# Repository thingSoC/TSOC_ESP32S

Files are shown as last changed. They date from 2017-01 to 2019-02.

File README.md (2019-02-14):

# TSOC_ESP32S - thingSoC Wi-Fi Radio Module :

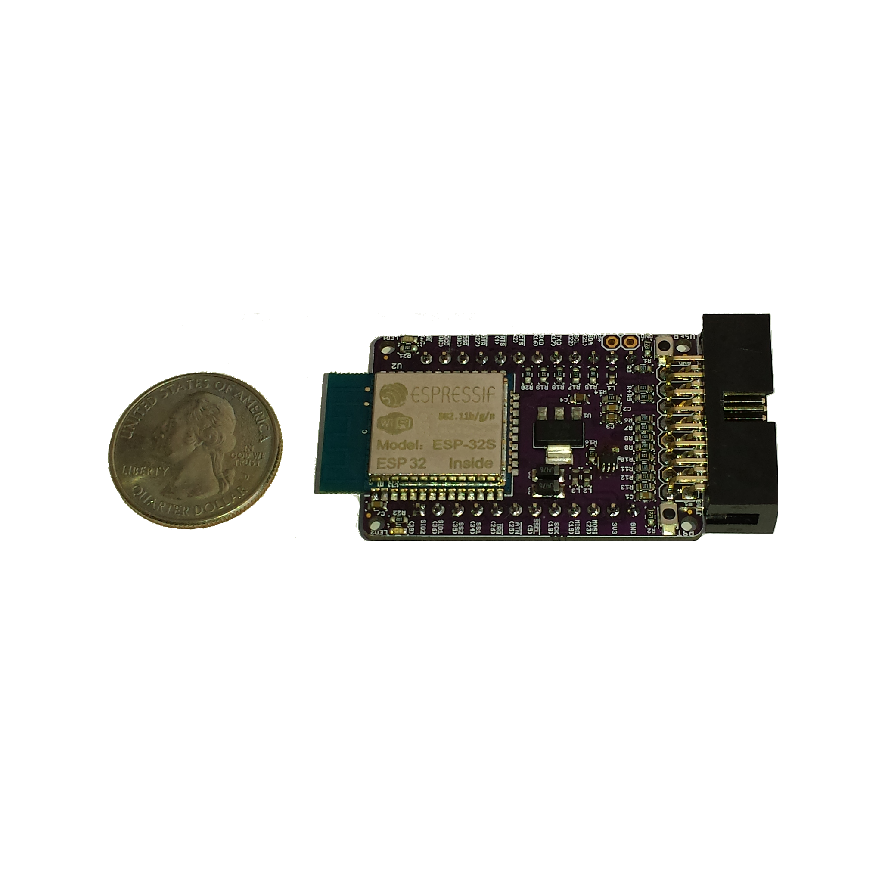
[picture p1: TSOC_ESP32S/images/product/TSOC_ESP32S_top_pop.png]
thingSoC TSOC_ESP32S
[TSOC_ESP32S](https://github.com/thingSoC/TSOC_ESP32S)

---------------------------------------

## TSOC_ESP32S Status <a name="TSOC_ESP32S_status"/>

**11/06/2016:** 
Revision 1.0 - Initial Layout released to OSHpark

---------------------------------------
## TSOC_ESP32S Model Images

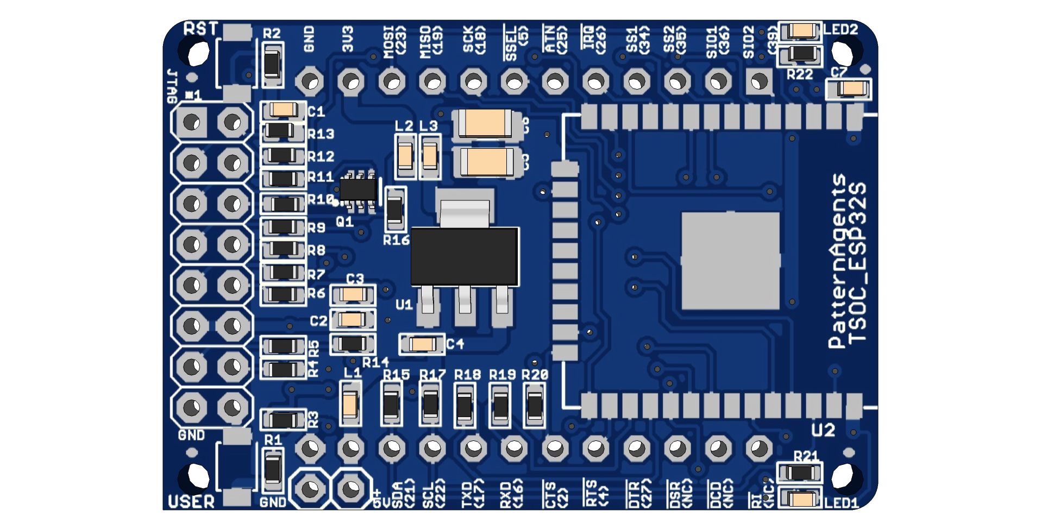
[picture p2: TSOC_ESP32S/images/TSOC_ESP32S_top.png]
thingSoC TSOC_ESP32S
[TSOC_ESP32S](https://github.com/thingSoC/TSOC_ESP32S)

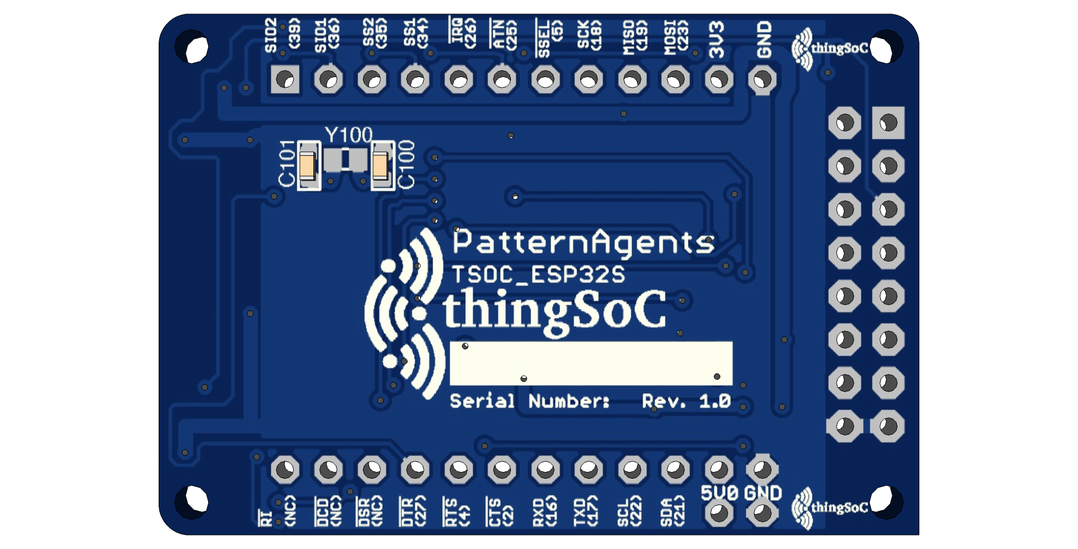
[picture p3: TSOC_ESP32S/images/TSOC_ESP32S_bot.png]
thingSoC TSOC_ESP32S
[TSOC_ESP32S](https://github.com/thingSoC/TSOC_ESP32S)

---------------------------------------

## TSOC_ESP32S Documentation Index <a name="TSOC_ESP32S_documentation_index"/>

[TSOC_ESP32S Project](http://thingsoc.github.io/projects/TSOC_ESP32S.html)

[TSOC_ESP32S Hardware](https://github.com/thingSoC/TSOC_ESP32S/tree/master/TSOC_ESP32S/hardware)

---------------------------------------

## thingSoC Documentation Index <a name="thingSoC_documentation_index"/>

[thingSoC Organization Website](http://thingSoC.github.io)

[thingSoC FAQ - Frequently Asked Questions](http://thingsoc.github.io/support/faq.html)

---------------------------------------

[thingSoC 
*thingSoC*](http://thingsoc.github.io)

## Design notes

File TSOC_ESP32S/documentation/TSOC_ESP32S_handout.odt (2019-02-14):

thingSoC ESP32S Board

Thank you for purchasing a TSOC_ESP32S board!
Please see the Getting Started Guide at :
https://github.com/thingSoC/TSOC_ESP32S (https://github.com/thingSoC/TSOC_NEOLED)
It has complete instructions and examples to download.

thingSoC ESP32S Board

Thank you for purchasing a TSOC_ESP32S board!
Please see the Getting Started Guide at :
https://github.com/thingSoC/TSOC_ESP32S (https://github.com/thingSoC/TSOC_NEOLED)
It has complete instructions and examples to download.

thingSoC ESP32S Board

Thank you for purchasing a TSOC_ESP32S board!
Please see the Getting Started Guide at :
https://github.com/thingSoC/TSOC_ESP32S (https://github.com/thingSoC/TSOC_NEOLED)
It has complete instructions and examples to download.

thingSoC ESP32S Board

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

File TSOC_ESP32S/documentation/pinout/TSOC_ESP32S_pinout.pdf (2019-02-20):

Sheet1

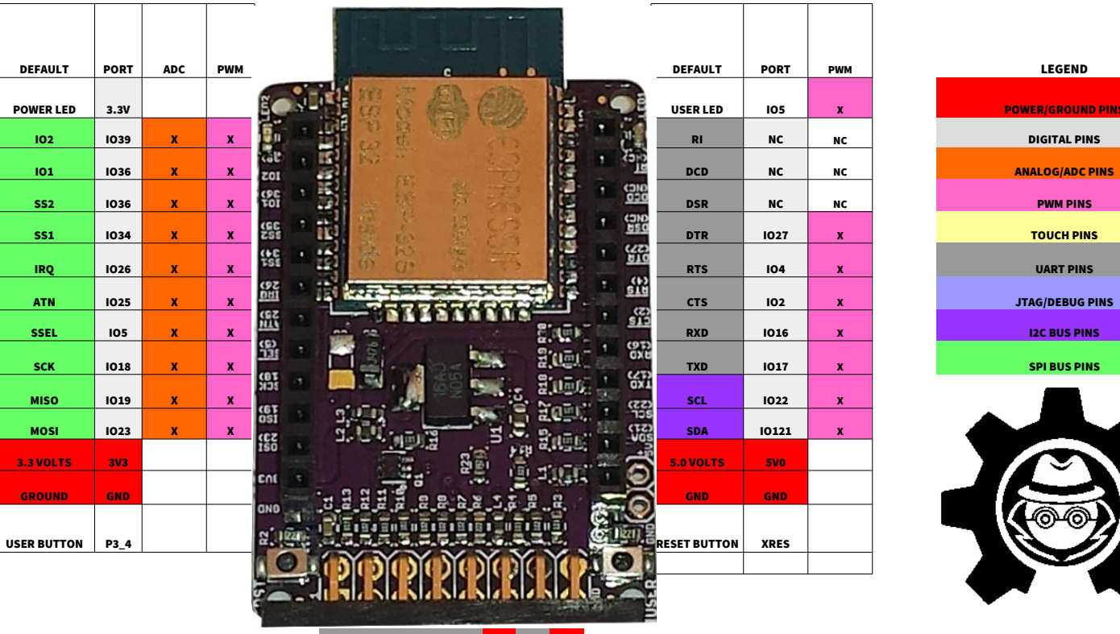
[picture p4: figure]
DIGITAL PINS; DCD; ANALOG/ADC PINS; DSR; PWM PINS; DTR; TOUCH PINS; IRQ; RTS; UART PINS; ATN; CTS; JTAG/DEBUG PINS; SSEL; RXD; I2C BUS PINS; SCK; TXD; SPI BUS PINS; MISO; SCL; MOSI; SDA; 3.3 VOLTS; 5.0 VOLTS; GROUND; GND; USER BUTTON; RESET BUTTON; XRES

Page 1

DEFAULT | PORT | ADC | PWM | DEFAULT | PORT | PWM | LEGEND
POWER LED | 3.3V | | | USER LED | IO5 | X | POWER/GROUND PINS

DSR1
RTS1

DTR1

TXD1 (IO3)

RXD1 (IO1)

5V0

CTS1
GND

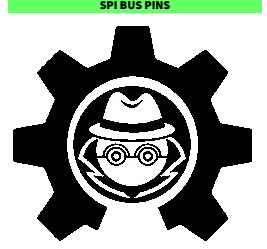
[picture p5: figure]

# ESP32 Wi-Fi Radio

DEBUG

SCL1 (IO12)
RESET#

SWDCLK (IO13)
SWDIO (IO14)

VCC

SDA1 (IO15)

GND

# http://github.com/thingSoC

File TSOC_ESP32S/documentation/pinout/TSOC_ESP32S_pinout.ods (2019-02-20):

DEFAULT | PORT | ADC | PWM |  |  |  |  |  |  |  |  | DEFAULT | PORT | PWM | LEGEND
POWER LED | 3.3V |  |  |  |  |  |  |  |  |  |  | USER LED | IO5 | X | POWER/GROUND PINS
IO2 | IO39 | X | X |  |  |  |  |  |  |  |  | RI | NC | NC | DIGITAL PINS
IO1 | IO36 | X | X |  |  |  |  |  |  |  |  | DCD | NC | NC | ANALOG/ADC PINS
SS2 | IO36 | X | X |  |  |  |  |  |  |  |  | DSR | NC | NC | PWM PINS
SS1 | IO34 | X | X |  |  |  |  |  |  |  |  | DTR | IO27 | X | TOUCH PINS
IRQ | IO26 | X | X |  |  |  |  |  |  |  |  | RTS | IO4 | X | UART PINS
ATN | IO25 | X | X |  |  |  |  |  |  |  |  | CTS | IO2 | X | JTAG/DEBUG PINS
SSEL | IO5 | X | X |  |  |  |  |  |  |  |  | RXD | IO16 | X | I2C BUS PINS
SCK | IO18 | X | X |  |  |  |  |  |  |  |  | TXD | IO17 | X | SPI BUS PINS
MISO | IO19 | X | X |  |  |  |  |  |  |  |  | SCL | IO22 | X
MOSI | IO23 | X | X |  |  |  |  |  |  |  |  | SDA | IO121 | X
3.3 VOLTS | 3V3 |  |  |  |  |  |  |  |  |  |  | 5.0 VOLTS | 5V0
GROUND | GND |  |  |  |  |  |  |  |  |  |  | GND | GND
USER BUTTON | P3_4 |  |  |  |  |  |  |  |  |  |  | RESET BUTTON | XRES
 |  |  |  | DSR1 | RTS1 | DTR1 | TXD1 (IO3) | RXD1 (IO1) | 5V0 | CTS1 | GND |  |  |  | ESP32 Wi-Fi Radio
 |  |  |  | DEBUG | SCL1 (IO12) | RESET# | SWDCLK (IO13) | SWDIO (IO14) | VCC | SDA1 (IO15) | GND |  | http://github.com/thingSoC

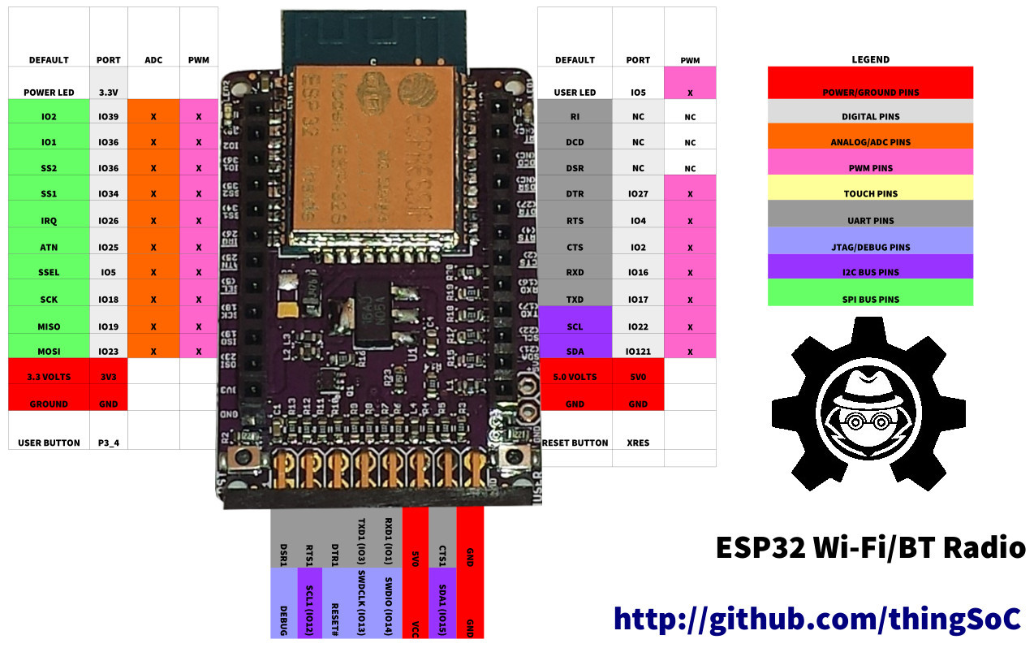
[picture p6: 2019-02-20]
TSOC_ESP32S/documentation/pinout/TSOC_ESP32S_pinout.jpg

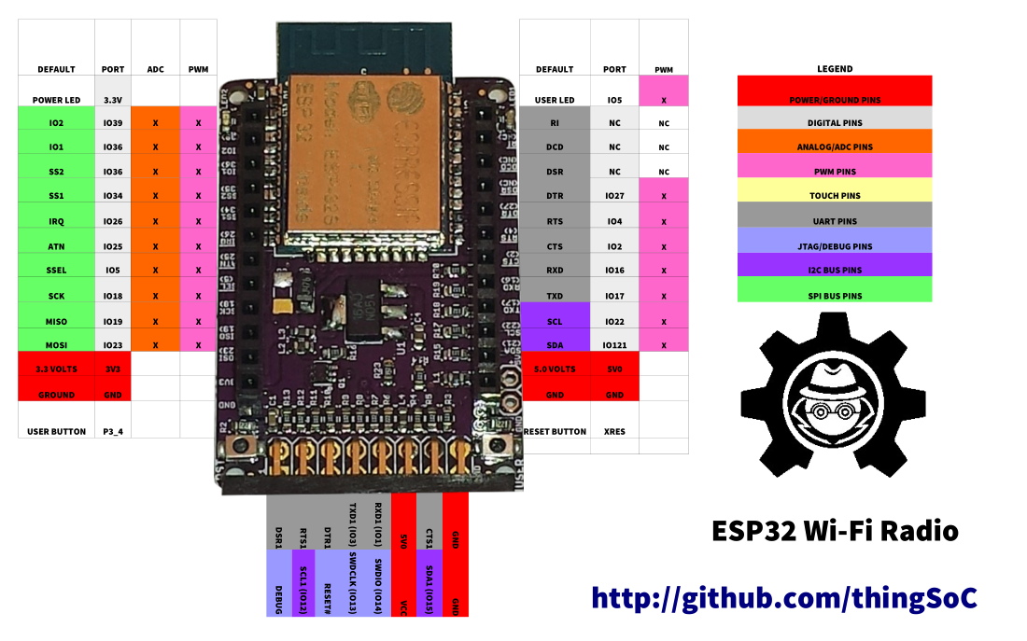
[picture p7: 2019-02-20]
TSOC_ESP32S/documentation/pinout/TSOC_ESP32S_pinout.png

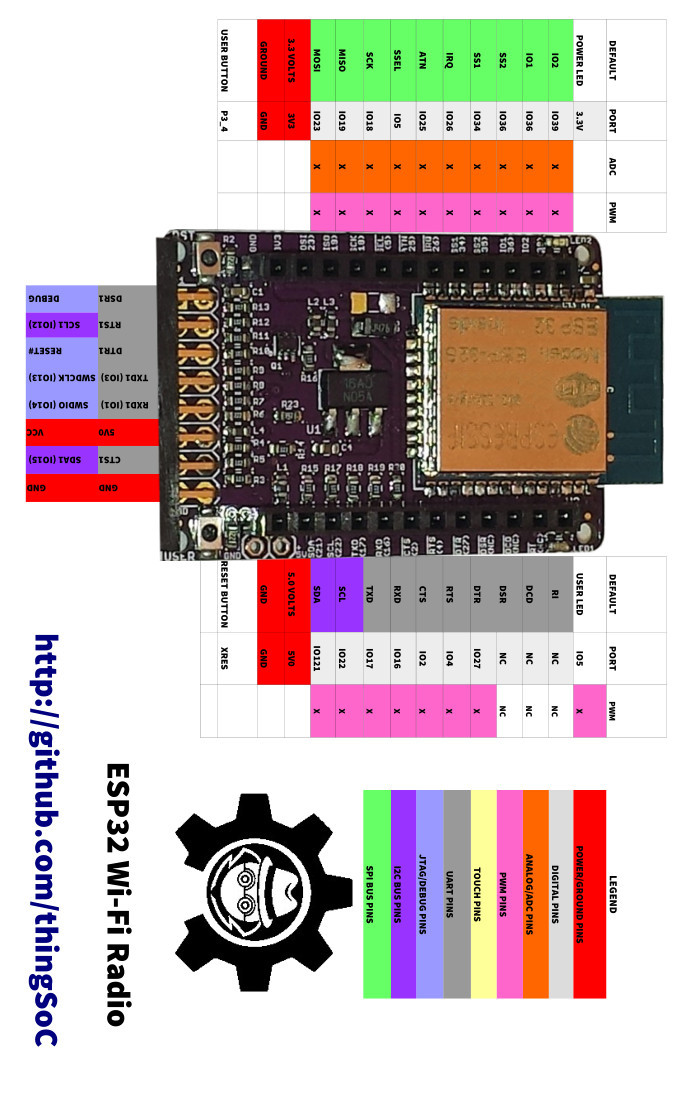
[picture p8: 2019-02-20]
TSOC_ESP32S/documentation/pinout/TSOC_ESP32S_pinout_long.jpg

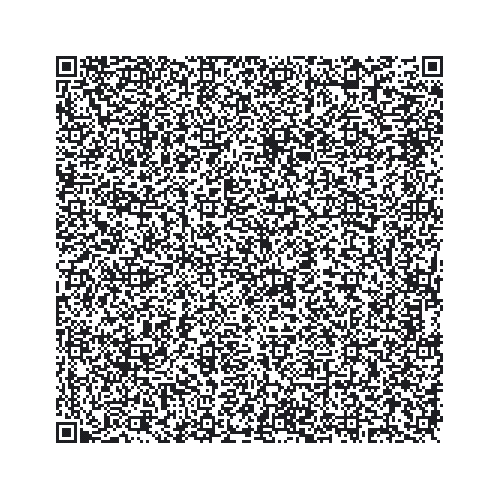
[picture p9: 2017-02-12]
TSOC_ESP32S/images/product/Grovey_ESP32_RTC_Blynk_Clone.png

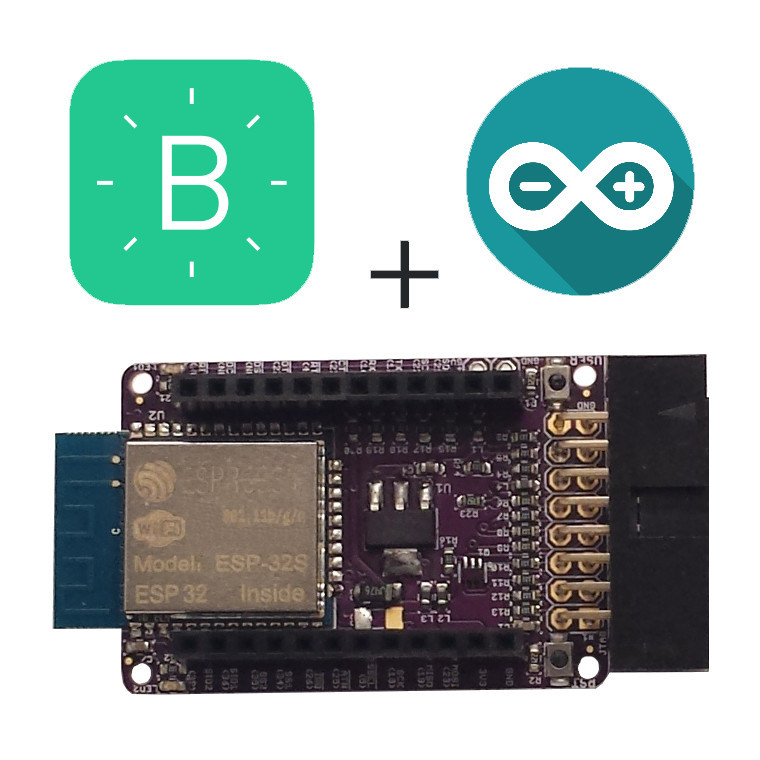
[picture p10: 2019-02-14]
TSOC_ESP32S/images/product/BlynkArduinoESP32.jpg

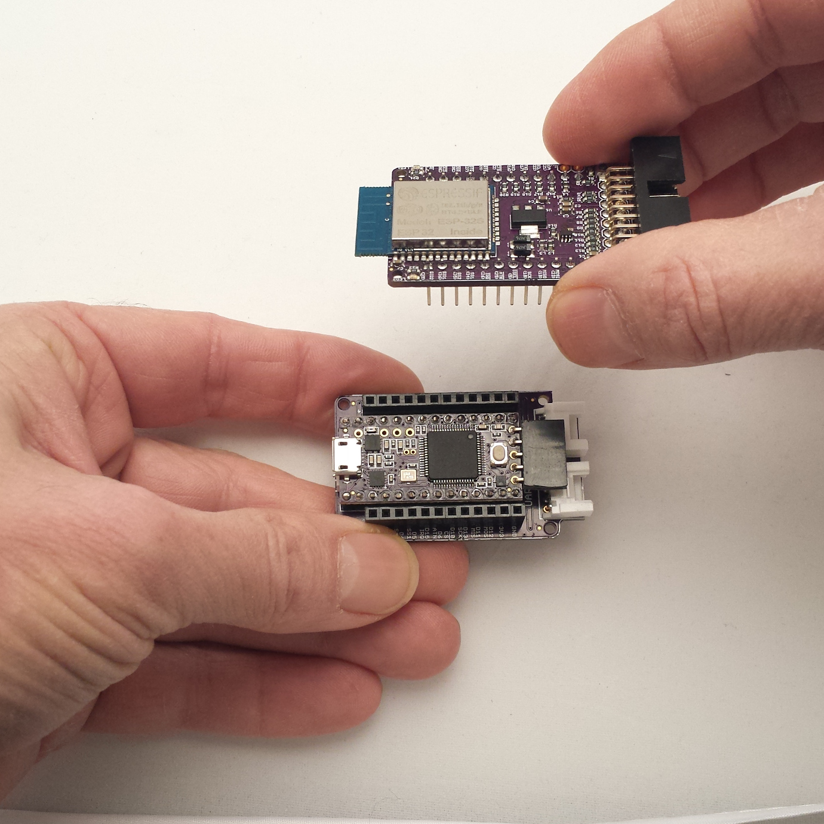
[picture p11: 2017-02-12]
TSOC_ESP32S/images/product/ESP32_Teensy.jpg

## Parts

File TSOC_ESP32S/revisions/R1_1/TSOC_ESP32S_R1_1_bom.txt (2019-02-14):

Partlist exported from U:/PatternAgents/eagle/TSOC_Modules/TSOC_ESP32S/TSOC_ESP32S/revisions/R1_1/TSOC_ESP32S.sch at 3/20/2017

Qty Value              Device                               Package     Parts                                          Description
-----------------------------------------------------------------------------------------------------------------------------------
1   CJT1117-3.3-SOT223 PMIC-CJT1117-3.3(SOT223)             SOT-223     U1                                                310030097                           
1   ESP-32S            ESP-32S                              ESP-32S     U2                                                ESP-32S                                    
2   220R               SMD-RES-220R-5%-1/10W(0603)          R0603       R1, R2                                            301010163                           
7   10K 1/10W          SMD-RES-10K-5%-1/10W(0603)           R0603       R3, R4, R13, R14, R15, R16, R17                   301010293                           
11  1K 1/10W           SMD-RES-1K-5%-1/10W(0603)            R0603       R5, R7, R8, R9, R10, R11, R12, R18, R19, R21, R22 301010291                           
1   1.8K               SMD-RES-1.8K-1%-1/10W(0603)          R0603       R6                                                301010254                           
1   3.3K               SMD-RES-3.3K-1%-1/10W(0603)          R0603       R23                                               301010251                           
2   100nf              CERAMIC-100NF-50V-10%-X7R(0603)      C0603       C1.C7                                             302010138                           
1   10uf               CERAMIC-10UF-10V-10%-X5R(0603)       C0603       C4                                                302010103                           
1   47u                CAPACITOR-1206                       C1206       C5, C6                                            302010183                          
3   330OHM-500MA       SMD-FERRITE-CHIP-120-OHM-500MA(0603) L0603       L1, L2, L3                                        303030001                           
2   B3U-1000P-2P-SMD   SMD-BUTTON(2P-3.0X2.5X1.2+0.4MM)     SW2-2.6-3   RST, USER                                         311020047                           
1   YELLOW-0603        SMD-LED-CLEAR-YELLOW(0603)           LED-0603    LED1                                              304090044                           
1   GREEN-0603         SMD-LED-CLEAR-GREEN(0603)            LED-0603    LED2                                              304090043                           
1   BSS138PS           BSS138PS                             SOT363      Q1                                                BSS138PS                 
1   M08X2              302-R161 (ED105350ND)                2X08        JTAG                                              302-R161 
2   M12                PPTC121LFBN-RC                       1X12        J2, J3                                            PPTC121LFBN-RC
-----------------------------------------------------------------------------------------------------------------------------------
Do NOT Populate
-----------------------------------------------------------------------------------------------------------------------------------
1   M02                M02PTH                               1X02        J1                                                320020016
1   10K 1/10W          SMD-RES-10K-5%-1/10W(0603)           R0603       R20                                               301010293
1   47u                CAPACITOR-1206                       C1206       C6                                                302010183
1   330OHM-500MA       SMD-FERRITE-CHIP-120-OHM-500MA(0603) L0603       L4                                                303030001                           
2   12pf               CERAMIC-12PF-50V-5%-NPO(0603)        C0603       C100, C101                                        302010067                           
1   3.2768KHZ          SMD-CRYSTAL-32.768KHZ-12.5PF-)       X2-SMD      Y100                                              306010020

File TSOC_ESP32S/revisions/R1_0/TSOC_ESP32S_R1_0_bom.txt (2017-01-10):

Partlist exported from U:/PatternAgents/eagle/TSOC_Modules/TSOC_ESP32S/TSOC_ESP32S/TSOC_ESP32S.sch at 11/26/2016 3:32:25 PM

Qty Value              Device                                                Package                   Parts                                          Description                         
2                      M01PTH                            1X01    5V0, GND                                       Header 1                            
1                      M08X2                            2X8     JTAG                                                
3   100nf              CERAMIC-100NF-50V-10%-X7R(0603)  C0603   C1, C3 C7,                                     302010138                           
10  10K 1/10W          SMD-RES-10K-5%-1/10W(0603)       R0603   R3, R4, R10, R11, R13, R14, R15, R16, R17, R20 301010293                           
1   10uf               CERAMIC-10UF-10V-10%-X5R(0603)   C0603   C4                                             302010103                           
2   12pf               CERAMIC-12PF-50V-5%-NPO(0603)    C0603   C100, C101                                     302010067                           
10  1K 1/10W           SMD-RES-1K-5%-1/10W(0603)        R0603   R5, R6, R7, R8, R9, R12, R18, R19, R21, R22    301010291                           
1   1uf                CERAMIC-1UF-25V-10%-X7R(0603)    C0603   C2                                             302010139                           
2   220R               SMD-RES-220R-5%-1/10W(0603)      R0603   R1, R2                                         301010163                           
1   3.2768KHZ          SMD-CRYSTAL-32.768KHZ-X2-SMD     SMD     Y100                                           306010020                           
3   330OHM-500MA       SMD-FERRITE-120-OHM-500MA(0603)  L0603   L1, L2, L3                                     303030001                           
2   47u                CAPACITOR-1206                   C1206   C5, C6                                         Capacitors                          
2   B3U-1000P-2P-SMD   SMD-BUTTON(2P-3.0X2.5X1.2+0.4MM) SW2-2.6 RST, USER                                      311020047                           
1   CJT1117-3.3-SOT223 PMIC-CJT1117-3.3(SOT223)         SOT-223 U1                                             310030097                           
1   ESP-32S            ESP-32S                          ESP-32S U2                                                                                 
1   GREEN-0603         SMD-LED-CLEAR-GREEN(0603)        0603    LED2                                           304090043                           
1   BSS138PS           BSS138PS                         SOT363  Q1                                             Dual N-Channel Mosfet                
1   TSOC-PCB-SINGLE    TSOC-PCB-SINGLE                  TSOC-BB BRD                                            thingSoC PCB Outlines               
1   YELLOW-0603        SMD-LED-CLEAR-YELLOW(0603)       0603    LED1                                           304090044

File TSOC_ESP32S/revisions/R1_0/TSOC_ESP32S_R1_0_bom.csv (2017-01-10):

Part | Value | Device | Package | Description
5V0 |  | M01PTH | 1X01 | Header 1
C1 | 100nf | CERAMIC-100NF-50V-10%-X7R(0603) | C0603 | 302010138
C2 | 1uf | CERAMIC-1UF-25V-10%-X7R(0603) | C0603 | 302010139
C3 | 100nf | CERAMIC-100NF-50V-10%-X7R(0603) | C0603 | 302010138
C4 | 10uf | CERAMIC-10UF-10V-10%-X5R(0603) | C0603 | 302010103
C5 | 47u | CAPACITOR-1206 | C1206 | Capacitors
C6 | 47u | CAPACITOR-1206 | C1206 | Capacitors
C7 | 100nf | CERAMIC-10UF-10V-10%-X5R(0603) | C0603 | 302010103
C100 | 12pf | CERAMIC-12PF-50V-5%-NPO(0603) | C0603 | 302010067
C101 | 12pf | CERAMIC-12PF-50V-5%-NPO(0603) | C0603 | 302010067
GND |  | M01PTH | 1X01 | Header 1
JTAG |  | M08X2 | 2X8 | .1 headers, two rows of 8 each"
L1 | 330OHM-500MA | SMD-FERRITE-CHIP-120-OHM-500MA(0603) | L0603 | 303030001
L2 | 330OHM-500MA | SMD-FERRITE-CHIP-120-OHM-500MA(0603) | L0603 | 303030001
L3 | 330OHM-500MA | SMD-FERRITE-CHIP-120-OHM-500MA(0603) | L0603 | 303030001
LED1 | YELLOW-0603 | SMD-LED-CLEAR-YELLOW(0603) | LED-0603 | 304090044
LED2 | GREEN-0603 | SMD-LED-CLEAR-GREEN(0603) | LED-0603 | 304090043
Q1 | MMBT2222A | MMDT3904 | SOT363 | Dual NPN transistor
R1 | 220R | SMD-RES-220R-5%-1/10W(0603) | R0603 | 301010163
R2 | 220R | SMD-RES-220R-5%-1/10W(0603) | R0603 | 301010163
R3 | 10K 1/10W | SMD-RES-10K-5%-1/10W(0603) | R0603 | 301010293
R4 | 10K 1/10W | SMD-RES-10K-5%-1/10W(0603) | R0603 | 301010293
R5 | 1K 1/10W | SMD-RES-1K-5%-1/10W(0603) | R0603 | 301010291
R6 | 1K 1/10W | SMD-RES-1K-5%-1/10W(0603) | R0603 | 301010291
R7 | 1K 1/10W | SMD-RES-1K-5%-1/10W(0603) | R0603 | 301010291
R8 | 1K 1/10W | SMD-RES-1K-5%-1/10W(0603) | R0603 | 301010291
R9 | 1K 1/10W | SMD-RES-1K-5%-1/10W(0603) | R0603 | 301010291
R10 | 10K 1/10W | SMD-RES-10K-5%-1/10W(0603) | R0603 | 301010293
R11 | 10K 1/10W | SMD-RES-10K-5%-1/10W(0603) | R0603 | 301010293
R12 | 1K 1/10W | SMD-RES-1K-5%-1/10W(0603) | R0603 | 301010291
R13 | 10K 1/10W | SMD-RES-10K-5%-1/10W(0603) | R0603 | 301010293
R14 | 10K 1/10W | SMD-RES-10K-5%-1/10W(0603) | R0603 | 301010293
R15 | 10K 1/10W | SMD-RES-10K-5%-1/10W(0603) | R0603 | 301010293
R16 | 10K 1/10W | SMD-RES-10K-5%-1/10W(0603) | R0603 | 301010293
R17 | 10K 1/10W | SMD-RES-10K-5%-1/10W(0603) | R0603 | 301010293
R18 | 1K 1/10W | SMD-RES-1K-5%-1/10W(0603) | R0603 | 301010291
R19 | 1K 1/10W | SMD-RES-1K-5%-1/10W(0603) | R0603 | 301010291
R20 | 10K 1/10W | SMD-RES-10K-5%-1/10W(0603) | R0603 | 301010293
R21 | 1K 1/10W | SMD-RES-1K-5%-1/10W(0603) | R0603 | 301010291
R22 | 1K 1/10W | SMD-RES-1K-5%-1/10W(0603) | R0603 | 301010291
RST | B3U-1000P-2P-SMD | SMD-BUTTON(2P-3.0X2.5X1.2+0.4MM)-B3U-1000P-2P-SMD | SW2-2.6-3.0X2.5X1.2+0.4MM | 311020047
U1 | CJT1117-3.3-SOT223 | PMIC-CJT1117-3.3(SOT223) | SOT-223 | 310030097
U2 | ESP-32S | ESP-32S | ESP-32S
USER | B3U-1000P-2P-SMD | SMD-BUTTON(2P-3.0X2.5X1.2+0.4MM)-B3U-1000P-2P-SMD | SW2-2.6-3.0X2.5X1.2+0.4MM | 311020047
Y100 | 3.2768KHZ | SMD-CRYSTAL-32.768KHZ-12.5PF-20PPM-90K(2P-L2.0X1.2MM) | X2-SMD-L2.0X1.2X0.55MM | 306010020

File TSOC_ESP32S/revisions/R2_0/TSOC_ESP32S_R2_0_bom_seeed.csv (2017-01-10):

U1 | 310030097 | 1
U2 | 114990772 | 1
R1, R2 | 301010163 | 2
R3, R4, R10, R11, R13, R14, R15, R16, R17, R20 | 301010293 | 10
R5, R7, R8, R9, R12, R18, R19, R21, R22 | 301010291 | 9
R6 | 301010254 | 1
R23 | 301010251 | 1
C1, C3, C5 | 302010138 | 3
C2 | 302010103 | 1
C4 | 302020005 | 1
L1, L2, L3, L4 | 303030001 | 4
RST, USER | 311020047 | 2
LED1 | 304090044 | 1
LED2 | 304090043 | 1
Q1 | BSS138PS,115 | 1
J1 | 320020016 | 1
J2, J3 | PPTC121LFBN-RC | 2
JTAG | 302-R161 | 1

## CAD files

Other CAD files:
TSOC_ESP32S/eagleUp/TSOC_ESP32S.skp

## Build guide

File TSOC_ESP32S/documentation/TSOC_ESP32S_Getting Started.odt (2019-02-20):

Welcome to the thingSoC® ESP32S Wi-Fi Radio

The TSOC_ESP32S is a Wi-Fi Radio board, based on the Espressif ESP32 chip, in an Embedded Module format for the new thingSoC, Internet of Things open source hardware standard.

Getting Started :
The TSOC_ESP32S is very flexible, and there are a number of different ways to power and
reprogram the board, including Over the Air using a Li-Po battery, using a thingSoC USBUART,
or other "FTDI" type USB to UART adapters, as well as JTAG/SWD interfaces for "bare metal" programming.

Using the thingSoC USB to UART Adapter :

1) Plug the USBUART in the ESP32S and connect your USB cable to your computer.

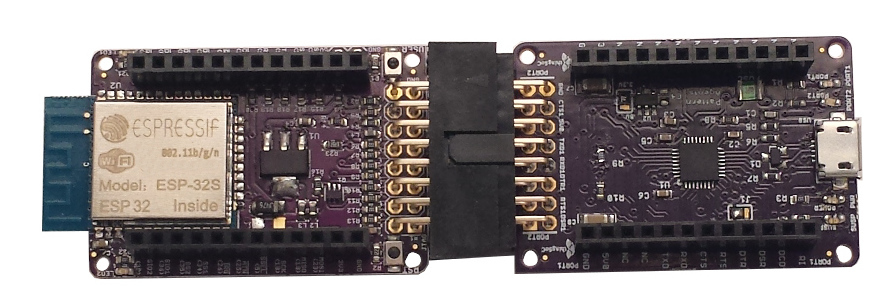
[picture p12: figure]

2) Note that the Green Power LED (LED2) illuminates, indicating the the ESP32S is powered
3) Check your Wi-Fi connections, and you should see "Ai-Thinker_ESP32_xxxxxx",
where the "xxxxxx" will be a unique number based on your MAC ID.
4) Connect to the "Ai-Thinker_ESP32_xxxxxx" as your Wi-Fi hot spot connection.

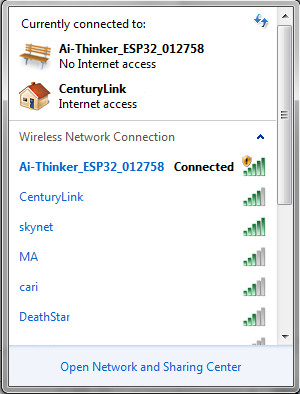
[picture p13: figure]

5) Now open a Web Browser and enter the URL "http://192.168.4.1" and you should see
the following test web page :

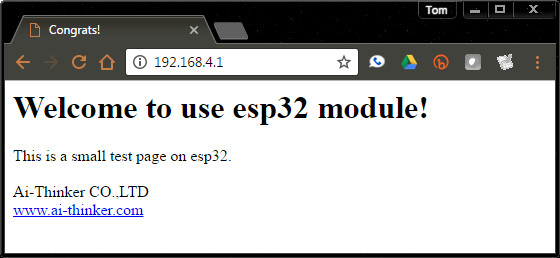
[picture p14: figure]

Using a Standard "FTDI" USB to UART Adapter :

1) Using a USB-to-UART adaper, like the Sparkfun 5.0 Volt "FTDI Basic", plug the ESP32S board
into your Windows, MAC, or Linux PC.

2) Make sure to use the "top" row of pins and align the Ground Pins on top as shown below.
THIS IS IMPORTANT, as you can DAMAGE your ESP32 board if connected incorrectly.

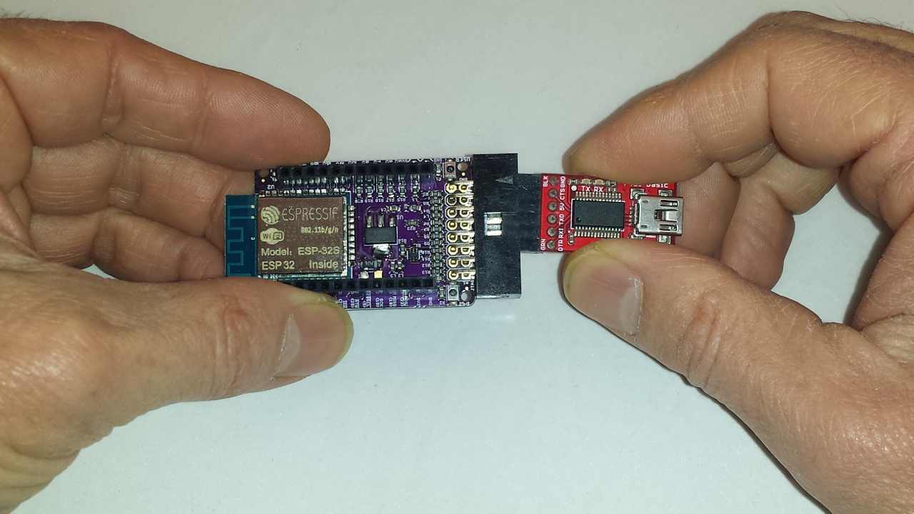
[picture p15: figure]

3) Make sure that you only use the "top" row of pins – the bottom row is for
3.3V JTAG/SWD programming only!

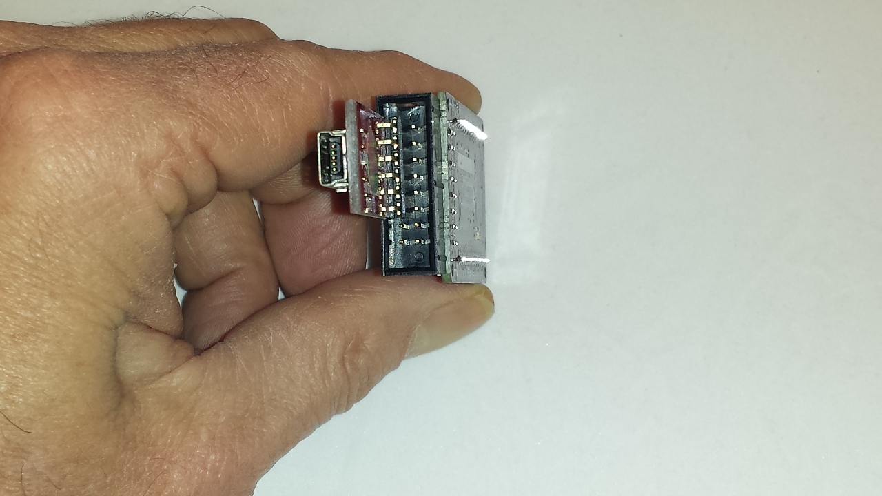
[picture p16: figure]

Using the thingSoC "Miniprog" JTAG Adapter :

The TSOC_ESP32S board can also be used with the thingSoC "Miniprog" adapter board,
as shown below. The thingSoC "Miniprog" adapter board breaks out the UART, I2C, and
the JTAG/SWD connections for testing and monitoring.

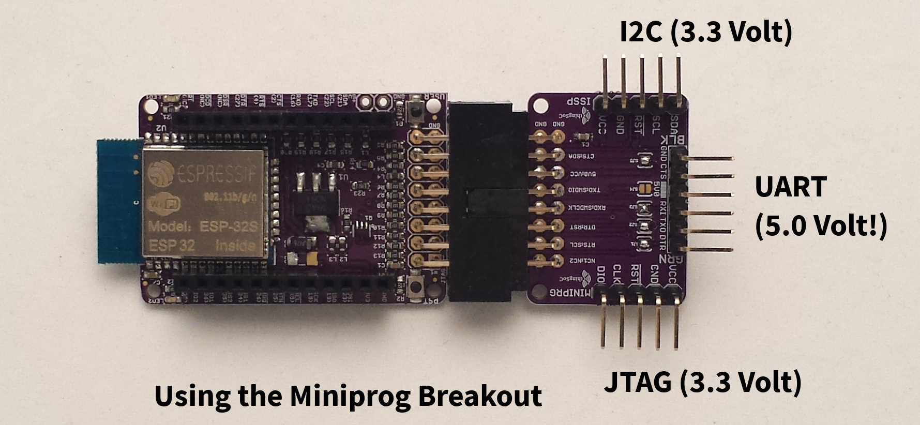
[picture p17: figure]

If you need to do "bare metal" JTAG programming, this provides a simple connection.

Lithium Battery Operation :
The TSOC_ESP32S board includes two(2) pins for connecting a 5V power adapter,
or directly connecting a 3.7 Volt to 4.2 Volt Lithium-Ion battery. That is all you need to do
to power up the board when using Over-the-Air (OTA) programming. We are working on separate application note for Over-the-Air (OTA) programming using the ESP32S.

Safe Handling Precautions :

1) Always remove/unplug all power before inserting or removing peripherals.
2) Always ground yourself by touching a ground point before handling your boards.
3) Use a static safe bag when transporting your TSOC_ESP32S board.

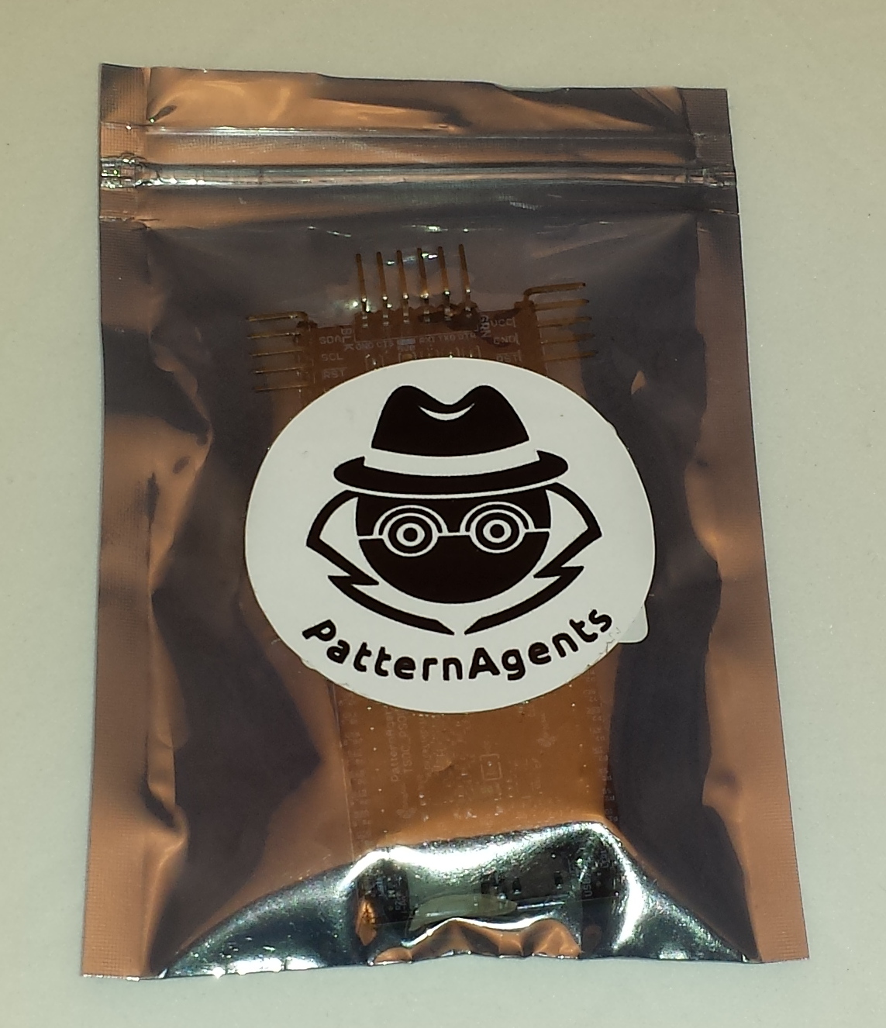
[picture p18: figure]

Adding Peripherals :
The TSOC_ESP32S board supports both thingSoC and Mikrobus peripherals.
1) Make sure to align the SQUARE/CUT edges of the boards together to insure that
the polarity is correct. Push down evenly to seat the boards in the socket.
2) Note that the "stacking pins" are somewhat longer by design, and there will be some
extra space between the boards when using stacking connectors.

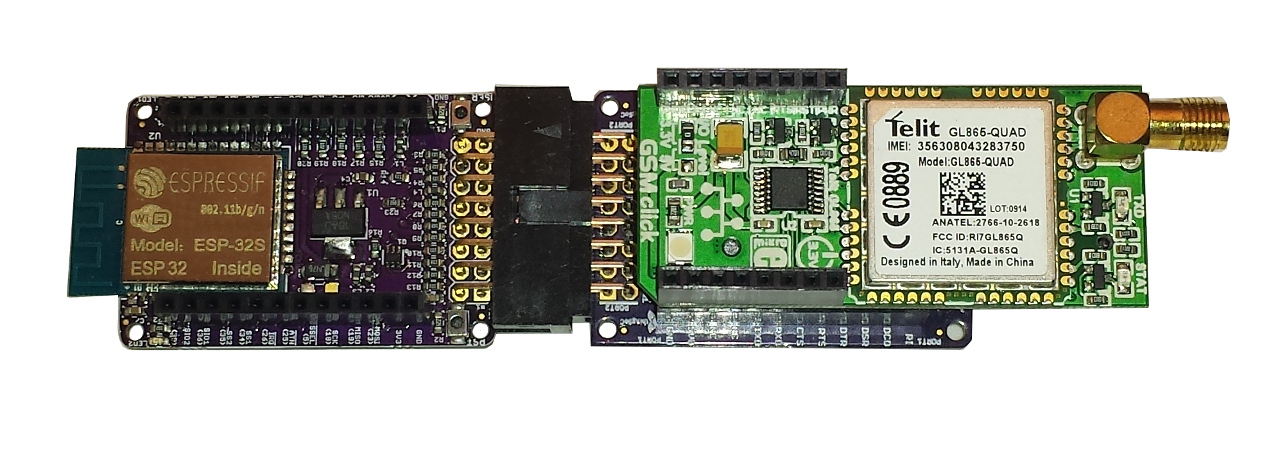
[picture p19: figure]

thingSoC ESP32S Optional Hardware :

The TSOC_ESP32S has footprints on the reverse side of the board that are not populated by default.
These include options for a Real-Time Clock Watch Crystal (32Khz) , and tank capacitors.
Add these optional components if you require use of the onboard Real-Time Clock (RTC).


Complete documentation, including schematics, layouts, gerbers, and Bill of Materials (BOM) are available on the thingSoC website at :

https://github.com/thingSoC/TSOC_ESP32S/tree/master/TSOC_ESP32S (https://github.com/thingSoC/TSOC_PSoC4L/tree/master/TSOC_PSoC4L)

There is also a project Wiki available for asking questions and more information at :

https://github.com/thingSoC/TSOC_ESP32S/wiki (https://github.com/thingSoC/TSOC_PSoC4L/wiki)

thingSoC® ESP32S Features :

The TSOC_ESP32S is a low cost, embeddable module featuring an ESP32S device :

- Xtensa Dual-Core 32-bit LX6 microprocessor
- 160 or 240 MHz , performing at up to 600 DMIPS
- 520 KiB SRAM
- Wi-Fi 802.11b/g/n/e/i
- 12-bit SAR Anaalog to Digital Converter (18 Channels)
- 8-bit Digital to Analog Converter (2 Channels)
- Touch Sensing (10 Channels)
- Temperature Sensor
- SPI (4 Channels)
- I2S Audio (2 Channels)
- I2C (2 Channels)
- UART (3 Channels)
- SDIO/MMC Host (1 Channel)
- SDIO/SPI Slave (1 Channel)
- CAN Bus 2.0 (1 Channel)
- Power and USER LEDs
- Reset and Boot Mode Pushbuttons
- Optional 32Khz Crystal for Real-Time Clock
- thingSoC Compliant Module
- Mikrobus Compatible Module (http://www.mikroe.com/mikrobus/)


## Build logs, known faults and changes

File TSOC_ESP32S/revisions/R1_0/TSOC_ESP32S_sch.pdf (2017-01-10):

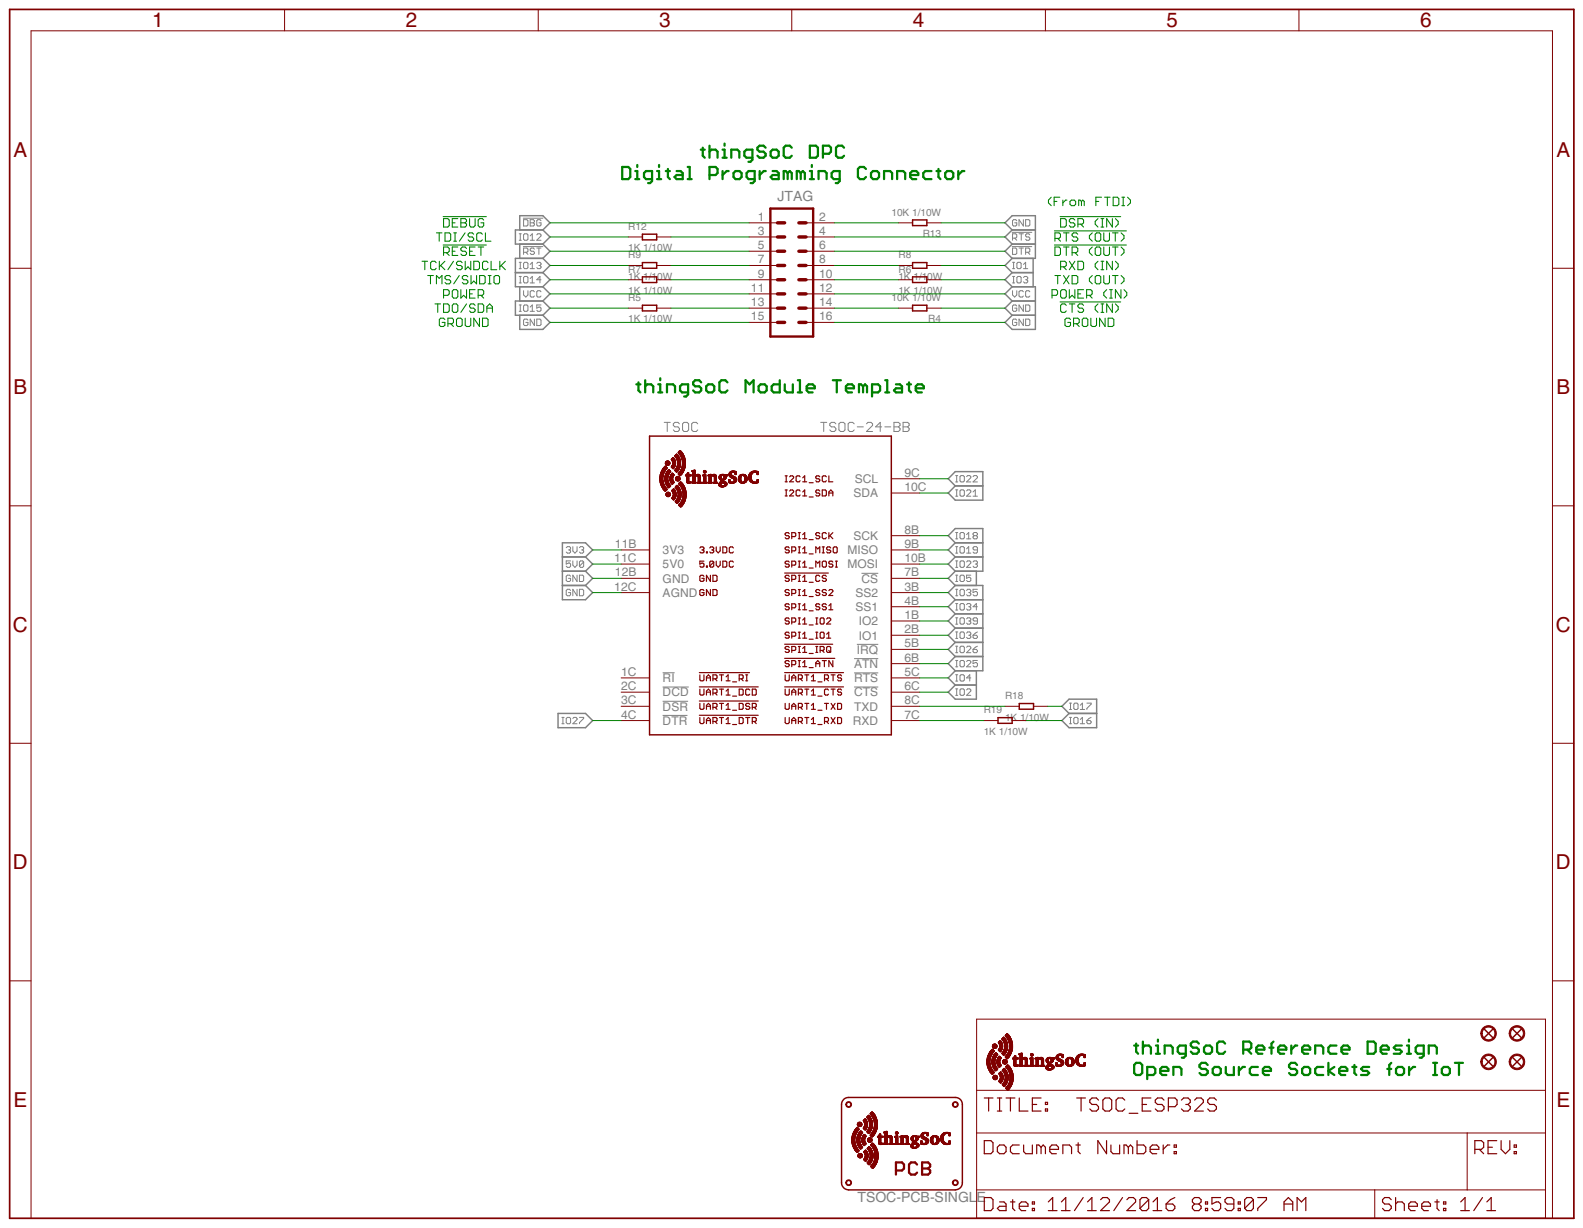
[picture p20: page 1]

100nf 1uf 1K 1/10W GND 100nf 330OHM-500MA GREEN-0603 GND100nf TSOC-PCB-SINGLE B3U-1000P-2P-SMD B3U-1000P-2P-SMD 10K 1/10W 10K 1/10W 10K 1/10W 10K 1/10W 10K 1/10W 10K 1/10W GND 10K 1/10W GND GND 220R 10K 1/10W 1K 1/10W GND YELLOW-0603 ESP-32S 10K 1/10W 47uGND 220R GND GND 3.2768KHZ 12pf 12pf GND GND CJT1117-3.3-SOT223 GND 10uf GND 47uGND 330OHM-500MA GND 330OHM-500MA 1K 1/10W 1K 1/10W 1K 1/10W 1K 1/10W 1K 1/10W 1K 1/10W 10K 1/10W 1K 1/10W 1K 1/10W C3C2 R22 C1 L2 LED2 C7 JTAG 1 2 3 4 5 6 7 8 9 10 11 12 13 14 15 16 1 1 2 2 RST1 1 2 2 USER R15 R17 ATN 6B RI 1C DCD 2C DSR 3C DTR 4C TXD 8C IO2 1B IO1 2B RTS 5C CTS 6C IRQ 5B SS2 3B SS1 4B CS 7B MOSI 10B MISO 9B SCK 8B GND 12B AGND 12C 3V3 11B RXD 7C SDA 10C SCL 9C 5V0 11C R16 Q1G$1 R10 R11 R14 R3 Q1G$2 R1 R20 R21 LED1 GND 1 3V3 2 EN 3 IO36/S_VP/ADC1_0 4 IO39/S_VN/ADC1_3 5 IO34/VDET1/ADC1_6 6 IO35/VDET2/ADC1_7 7 IO32/XTAL_32K/ADC1_4 8 IO33/XTAL_32K/ADC1_5 9 IO25/DAC1/ADC2_8 10 IO26/DAC2/ADC2_9 11 IO27/TOUCH7/ADC2_7 12 IO14/TOUCH6/ADC2_6 13 IO12/TOUCH5/ADC2_5 14 GND 15 IO13/TOUCH4/ADC2_4 16 SD2/SHD 17 SD3/SWP 18 CMD/SCS 19 GND 38 MOSI/IO23 37 SCL/IO22 36 TXD0/IO1 35 RXD0/IO3 34 SDA/IO21 33 NC 32 MISO/IO19 31 SCK/IO18 30 SS/IO5 29 TXD2IO17 28 RXD2/IO16 27 ADC2_0/TOUCH0/IO4 26 ADC2_1/TOUCH1/IO0 25 IO2 24 IO15/TOUCH3/ADC2_3 23 SD1/SDI 22 SD0/SDO 21 CLK/SCK 20 GND GND U2 R4 C6 R2 Y100 C101 C100 U1 GND 1 IN 3 OUT 2*2 C4C5 GND 5V0 L1 L3 R8R6 R12 R9R7R5 R13 R18 R19 VCC DTR RTS 3V3 IO0 ABCDE ABCDE 1 2 3 4 5 6 ABCDE ABCDE 1 2 3 4 5 6 ABCDE ABCDE 1 2 3 4 5 6 ABCDE ABCDE 1 2 3 4 5 6 GND GND GND GND GND GND GND GND GND Heartbeat LED Flash Programming & Reset Modes --------------------------------------------- | nDTR | nRTS | nRST | GPIO0 | --------------------------------------------- | 0 | 0 | 1 | 1 | | 0 | 1 | 1 | 0 | | 1 | 0 | 0 | 1 | | 1 | 1 | 1 | 1 | --------------------------------------------- 32,768 KHz Crystal (WCO/RTC Clock)

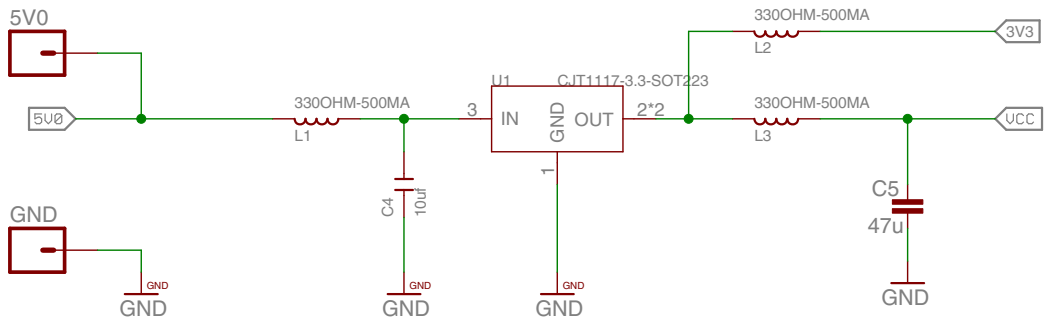
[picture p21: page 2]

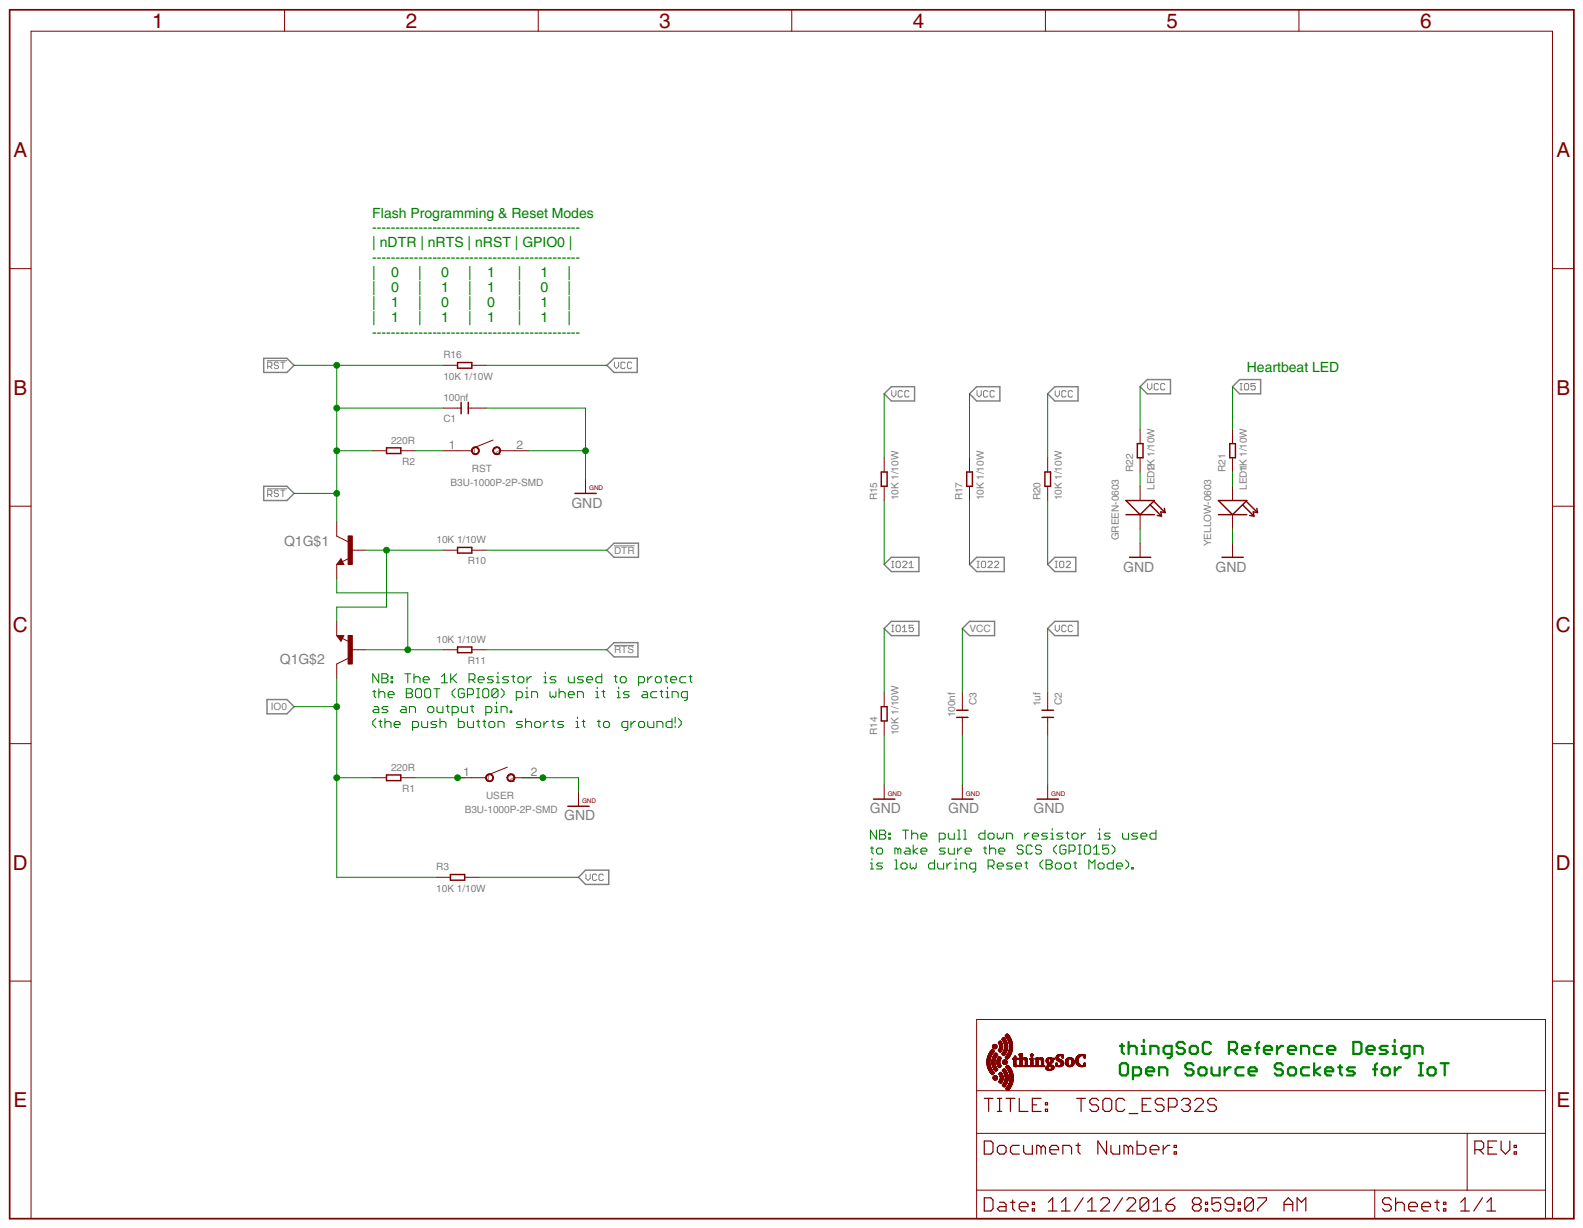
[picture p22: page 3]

100nf 1uf 1K 1/10W GND 100nf 330OHM-500MA GREEN-0603 GND100nf TSOC-PCB-SINGLE B3U-1000P-2P-SMD B3U-1000P-2P-SMD 10K 1/10W 10K 1/10W 10K 1/10W 10K 1/10W 10K 1/10W 10K 1/10W GND 10K 1/10W GND GND 220R 10K 1/10W 1K 1/10W GND YELLOW-0603 ESP-32S 10K 1/10W 47uGND 220R GND GND 3.2768KHZ 12pf 12pf GND GND CJT1117-3.3-SOT223 GND 10uf GND 47uGND 330OHM-500MA GND 330OHM-500MA 1K 1/10W 1K 1/10W 1K 1/10W 1K 1/10W 1K 1/10W 1K 1/10W 10K 1/10W 1K 1/10W 1K 1/10W C3C2 R22 C1 L2 LED2 C7 JTAG 1 2 3 4 5 6 7 8 9 10 11 12 13 14 15 16 1 1 2 2 RST1 1 2 2 USER R15 R17 ATN 6B RI 1C DCD 2C DSR 3C DTR 4C TXD 8C IO2 1B IO1 2B RTS 5C CTS 6C IRQ 5B SS2 3B SS1 4B CS 7B MOSI 10B MISO 9B SCK 8B GND 12B AGND 12C 3V3 11B RXD 7C SDA 10C SCL 9C 5V0 11C R16 Q1G$1 R10 R11 R14 R3 Q1G$2 R1 R20 R21 LED1 GND 1 3V3 2 EN 3 IO36/S_VP/ADC1_0 4 IO39/S_VN/ADC1_3 5 IO34/VDET1/ADC1_6 6 IO35/VDET2/ADC1_7 7 IO32/XTAL_32K/ADC1_4 8 IO33/XTAL_32K/ADC1_5 9 IO25/DAC1/ADC2_8 10 IO26/DAC2/ADC2_9 11 IO27/TOUCH7/ADC2_7 12 IO14/TOUCH6/ADC2_6 13 IO12/TOUCH5/ADC2_5 14 GND 15 IO13/TOUCH4/ADC2_4 16 SD2/SHD 17 SD3/SWP 18 CMD/SCS 19 GND 38 MOSI/IO23 37 SCL/IO22 36 TXD0/IO1 35 RXD0/IO3 34 SDA/IO21 33 NC 32 MISO/IO19 31 SCK/IO18 30 SS/IO5 29 TXD2IO17 28 RXD2/IO16 27 ADC2_0/TOUCH0/IO4 26 ADC2_1/TOUCH1/IO0 25 IO2 24 IO15/TOUCH3/ADC2_3 23 SD1/SDI 22 SD0/SDO 21 CLK/SCK 20 GND GND U2 R4 C6 R2 Y100 C101 C100 U1 GND 1 IN 3 OUT 2*2 C4C5 GND 5V0 L1 L3 R8R6 R12 R9R7R5 R13 R18 R19 VCC DTR RTS 3V3 IO0 ABCDE ABCDE 1 2 3 4 5 6 ABCDE ABCDE 1 2 3 4 5 6 ABCDE ABCDE 1 2 3 4 5 6 ABCDE ABCDE 1 2 3 4 5 6 GND GND GND GND GND GND GND GND GND Heartbeat LED Flash Programming & Reset Modes --------------------------------------------- | nDTR | nRTS | nRST | GPIO0 | --------------------------------------------- | 0 | 0 | 1 | 1 | | 0 | 1 | 1 | 0 | | 1 | 0 | 0 | 1 | | 1 | 1 | 1 | 1 | --------------------------------------------- 32,768 KHz Crystal (WCO/RTC Clock)

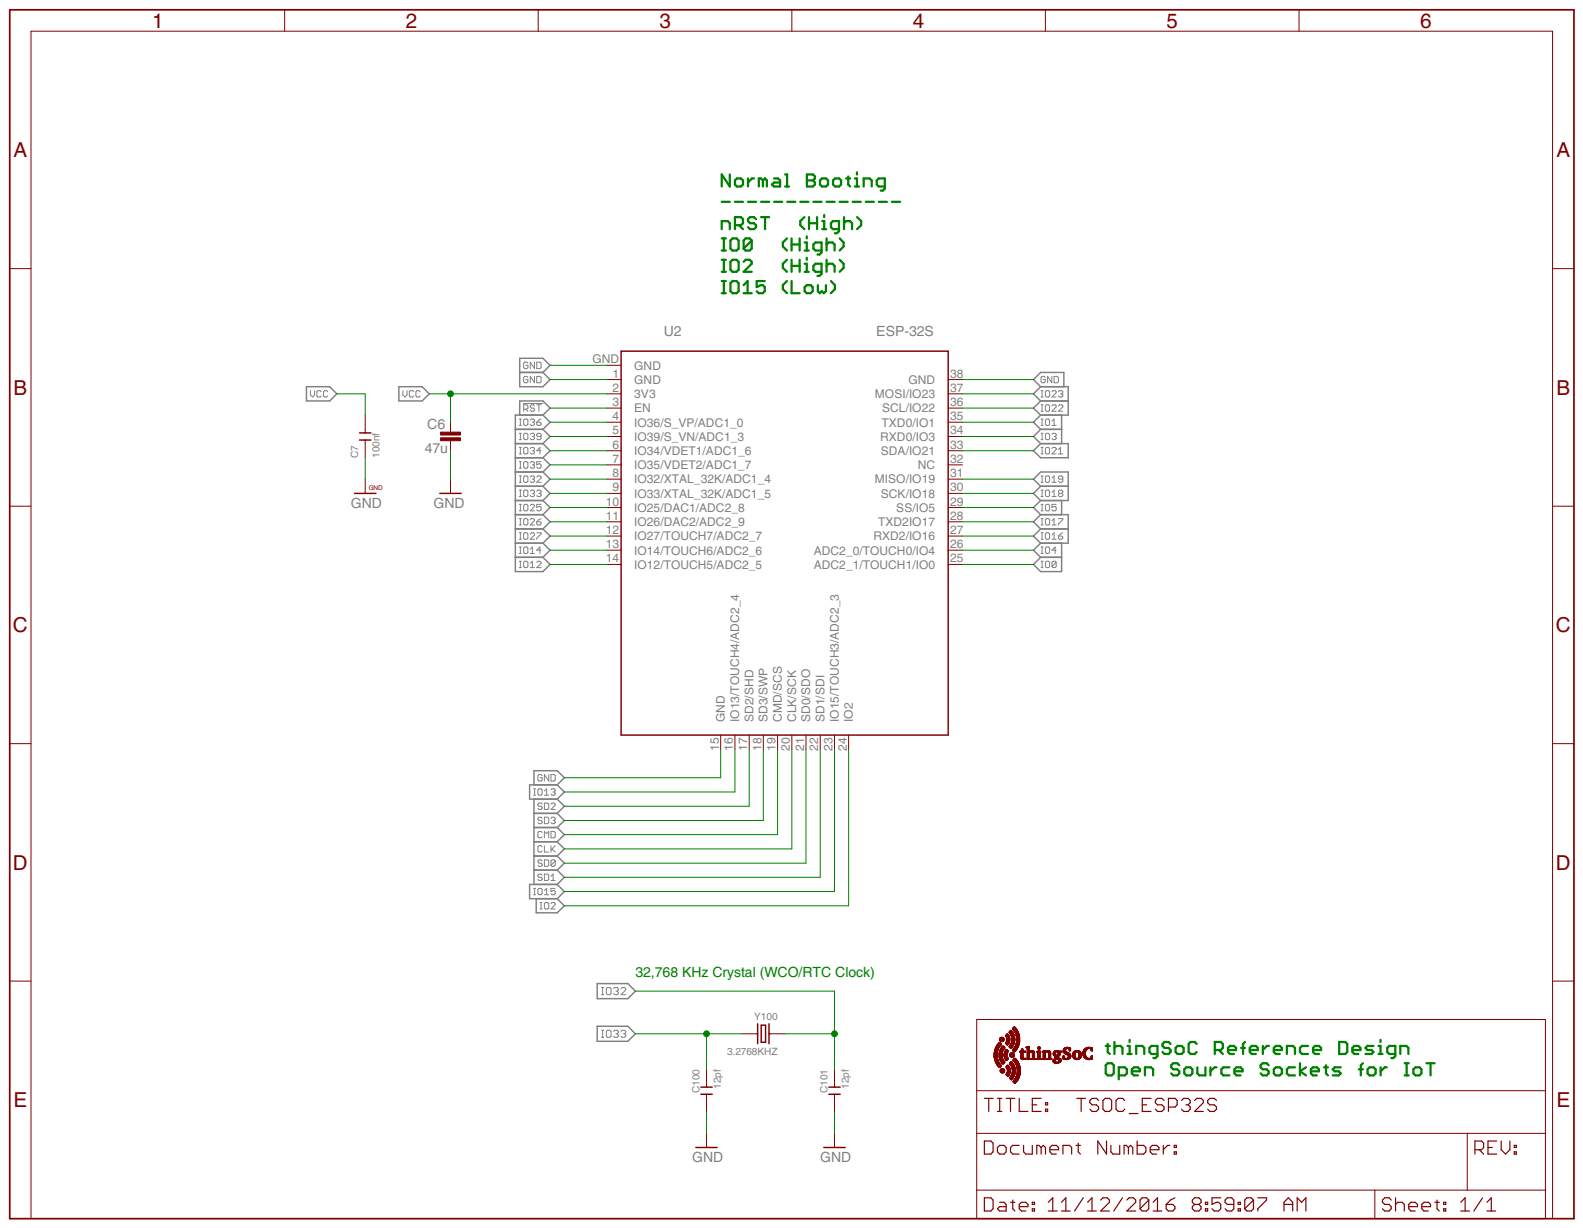
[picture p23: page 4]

100nf 1uf 1K 1/10W GND 100nf 330OHM-500MA GREEN-0603 GND100nf TSOC-PCB-SINGLE B3U-1000P-2P-SMD B3U-1000P-2P-SMD 10K 1/10W 10K 1/10W 10K 1/10W 10K 1/10W 10K 1/10W 10K 1/10W GND 10K 1/10W GND GND 220R 10K 1/10W 1K 1/10W GND YELLOW-0603 ESP-32S 10K 1/10W 47uGND 220R GND GND 3.2768KHZ 12pf 12pf GND GND CJT1117-3.3-SOT223 GND 10uf GND 47uGND 330OHM-500MA GND 330OHM-500MA 1K 1/10W 1K 1/10W 1K 1/10W 1K 1/10W 1K 1/10W 1K 1/10W 10K 1/10W 1K 1/10W 1K 1/10W C3C2 R22 C1 L2 LED2 C7 JTAG 1 2 3 4 5 6 7 8 9 10 11 12 13 14 15 16 1 1 2 2 RST1 1 2 2 USER R15 R17 ATN 6B RI 1C DCD 2C DSR 3C DTR 4C TXD 8C IO2 1B IO1 2B RTS 5C CTS 6C IRQ 5B SS2 3B SS1 4B CS 7B MOSI 10B MISO 9B SCK 8B GND 12B AGND 12C 3V3 11B RXD 7C SDA 10C SCL 9C 5V0 11C R16 Q1G$1 R10 R11 R14 R3 Q1G$2 R1 R20 R21 LED1 GND 1 3V3 2 EN 3 IO36/S_VP/ADC1_0 4 IO39/S_VN/ADC1_3 5 IO34/VDET1/ADC1_6 6 IO35/VDET2/ADC1_7 7 IO32/XTAL_32K/ADC1_4 8 IO33/XTAL_32K/ADC1_5 9 IO25/DAC1/ADC2_8 10 IO26/DAC2/ADC2_9 11 IO27/TOUCH7/ADC2_7 12 IO14/TOUCH6/ADC2_6 13 IO12/TOUCH5/ADC2_5 14 GND 15 IO13/TOUCH4/ADC2_4 16 SD2/SHD 17 SD3/SWP 18 CMD/SCS 19 GND 38 MOSI/IO23 37 SCL/IO22 36 TXD0/IO1 35 RXD0/IO3 34 SDA/IO21 33 NC 32 MISO/IO19 31 SCK/IO18 30 SS/IO5 29 TXD2IO17 28 RXD2/IO16 27 ADC2_0/TOUCH0/IO4 26 ADC2_1/TOUCH1/IO0 25 IO2 24 IO15/TOUCH3/ADC2_3 23 SD1/SDI 22 SD0/SDO 21 CLK/SCK 20 GND GND U2 R4 C6 R2 Y100 C101 C100 U1 GND 1 IN 3 OUT 2*2 C4C5 GND 5V0 L1 L3 R8R6 R12 R9R7R5 R13 R18 R19 VCC DTR RTS 3V3 IO0 ABCDE ABCDE 1 2 3 4 5 6 ABCDE ABCDE 1 2 3 4 5 6 ABCDE ABCDE 1 2 3 4 5 6 ABCDE ABCDE 1 2 3 4 5 6 GND GND GND GND GND GND GND GND GND Heartbeat LED Flash Programming & Reset Modes --------------------------------------------- | nDTR | nRTS | nRST | GPIO0 | --------------------------------------------- | 0 | 0 | 1 | 1 | | 0 | 1 | 1 | 0 | | 1 | 0 | 0 | 1 | | 1 | 1 | 1 | 1 | --------------------------------------------- 32,768 KHz Crystal (WCO/RTC Clock)

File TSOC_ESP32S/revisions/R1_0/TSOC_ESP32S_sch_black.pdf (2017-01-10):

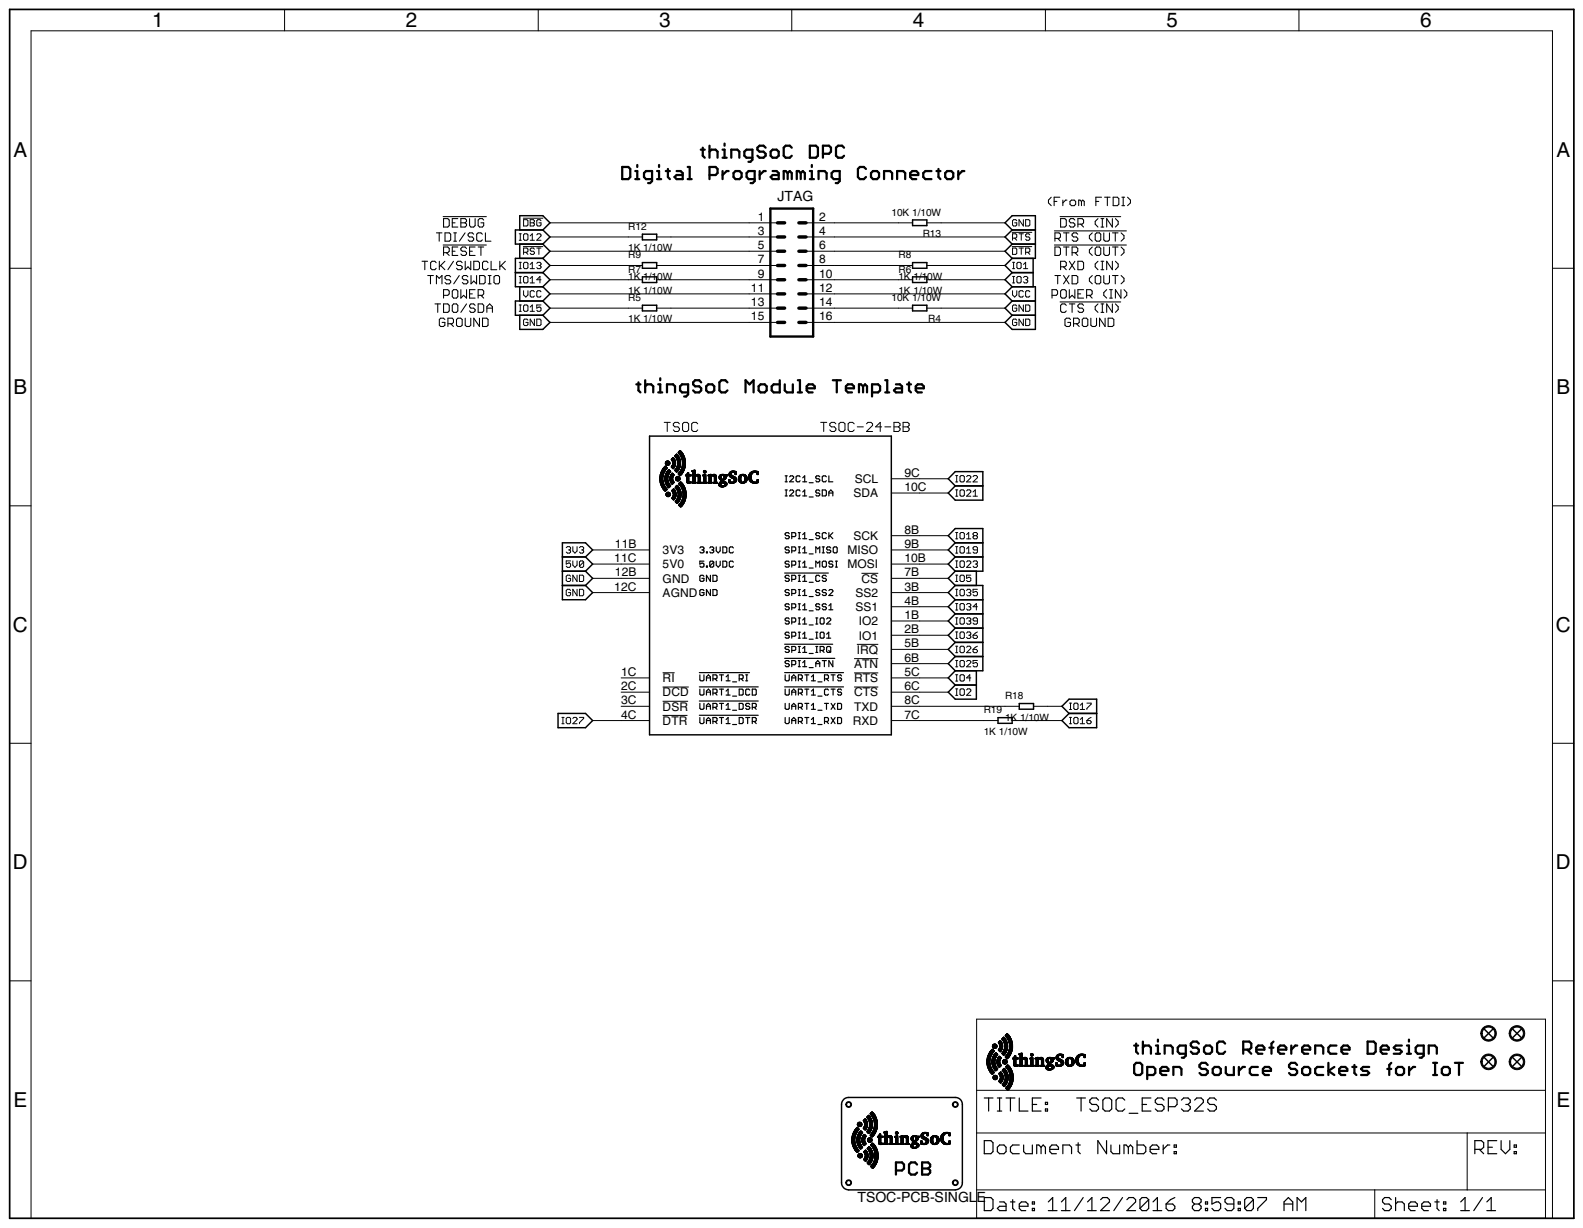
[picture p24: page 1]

100nf 1uf 1K 1/10W GND 100nf 330OHM-500MA GREEN-0603 GND100nf TSOC-PCB-SINGLE B3U-1000P-2P-SMD B3U-1000P-2P-SMD 10K 1/10W 10K 1/10W 10K 1/10W 10K 1/10W 10K 1/10W 10K 1/10W GND 10K 1/10W GND GND 220R 10K 1/10W 1K 1/10W GND YELLOW-0603 ESP-32S 10K 1/10W 47uGND 220R GND GND 3.2768KHZ 12pf 12pf GND GND CJT1117-3.3-SOT223 GND 10uf GND 47uGND 330OHM-500MA GND 330OHM-500MA 1K 1/10W 1K 1/10W 1K 1/10W 1K 1/10W 1K 1/10W 1K 1/10W 10K 1/10W 1K 1/10W 1K 1/10W C3C2 R22 C1 L2 LED2 C7 JTAG 1 2 3 4 5 6 7 8 9 10 11 12 13 14 15 16 1 1 2 2 RST1 1 2 2 USER R15 R17 ATN 6B RI 1C DCD 2C DSR 3C DTR 4C TXD 8C IO2 1B IO1 2B RTS 5C CTS 6C IRQ 5B SS2 3B SS1 4B CS 7B MOSI 10B MISO 9B SCK 8B GND 12B AGND 12C 3V3 11B RXD 7C SDA 10C SCL 9C 5V0 11C R16 Q1G$1 R10 R11 R14 R3 Q1G$2 R1 R20 R21 LED1 GND 1 3V3 2 EN 3 IO36/S_VP/ADC1_0 4 IO39/S_VN/ADC1_3 5 IO34/VDET1/ADC1_6 6 IO35/VDET2/ADC1_7 7 IO32/XTAL_32K/ADC1_4 8 IO33/XTAL_32K/ADC1_5 9 IO25/DAC1/ADC2_8 10 IO26/DAC2/ADC2_9 11 IO27/TOUCH7/ADC2_7 12 IO14/TOUCH6/ADC2_6 13 IO12/TOUCH5/ADC2_5 14 GND 15 IO13/TOUCH4/ADC2_4 16 SD2/SHD 17 SD3/SWP 18 CMD/SCS 19 GND 38 MOSI/IO23 37 SCL/IO22 36 TXD0/IO1 35 RXD0/IO3 34 SDA/IO21 33 NC 32 MISO/IO19 31 SCK/IO18 30 SS/IO5 29 TXD2IO17 28 RXD2/IO16 27 ADC2_0/TOUCH0/IO4 26 ADC2_1/TOUCH1/IO0 25 IO2 24 IO15/TOUCH3/ADC2_3 23 SD1/SDI 22 SD0/SDO 21 CLK/SCK 20 GND GND U2 R4 C6 R2 Y100 C101 C100 U1 GND 1 IN 3 OUT 2*2 C4C5 GND 5V0 L1 L3 R8R6 R12 R9R7R5 R13 R18 R19 VCC DTR RTS 3V3 IO0 ABCDE ABCDE 1 2 3 4 5 6 ABCDE ABCDE 1 2 3 4 5 6 ABCDE ABCDE 1 2 3 4 5 6 ABCDE ABCDE 1 2 3 4 5 6 GND GND GND GND GND GND GND GND GND Heartbeat LED Flash Programming & Reset Modes --------------------------------------------- | nDTR | nRTS | nRST | GPIO0 | --------------------------------------------- | 0 | 0 | 1 | 1 | | 0 | 1 | 1 | 0 | | 1 | 0 | 0 | 1 | | 1 | 1 | 1 | 1 | --------------------------------------------- 32,768 KHz Crystal (WCO/RTC Clock)

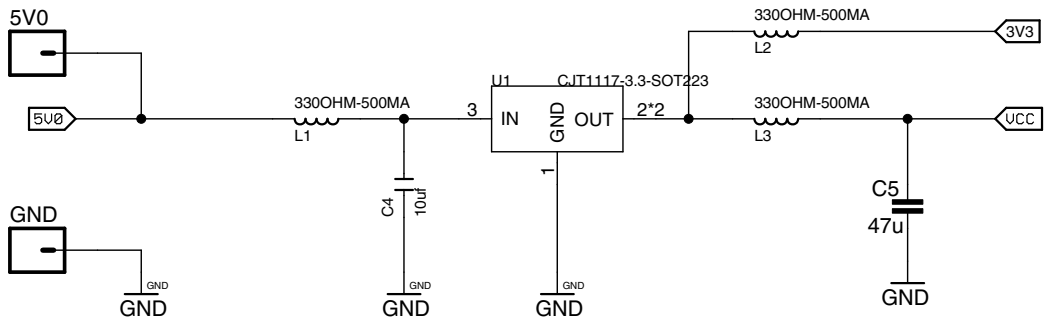
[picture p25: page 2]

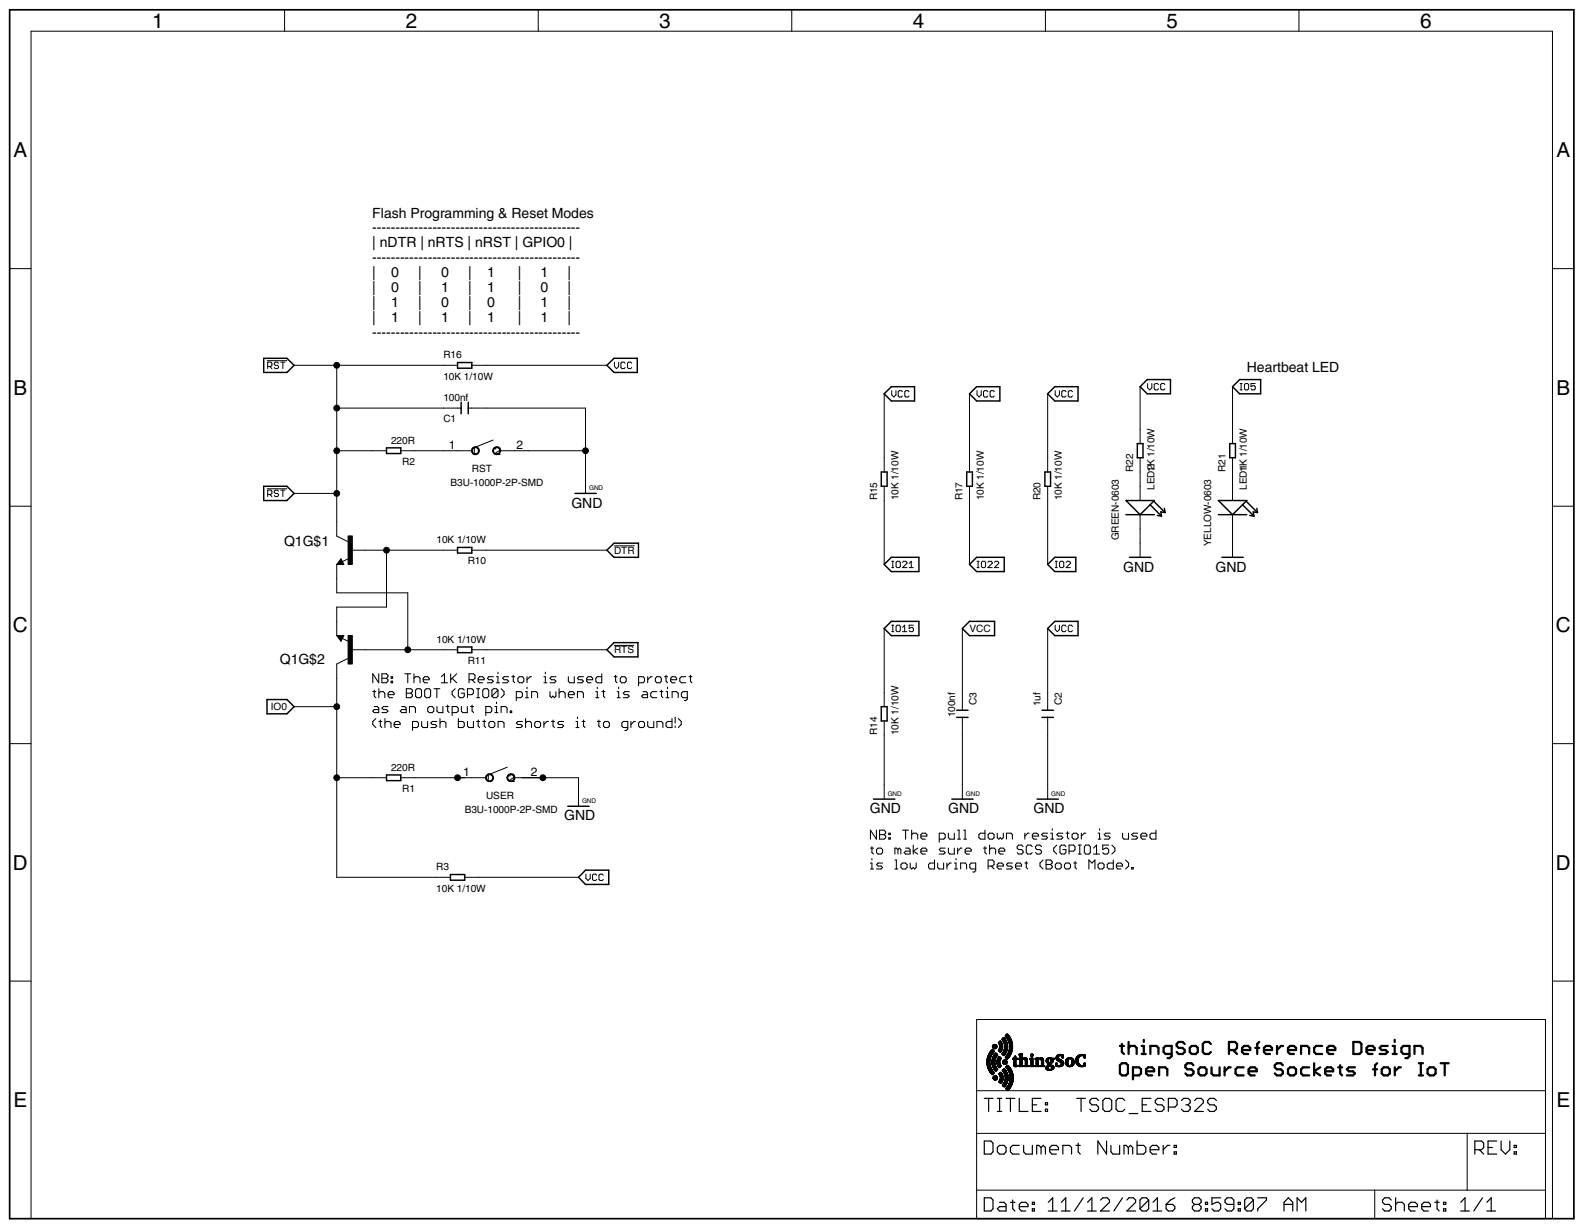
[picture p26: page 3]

100nf 1uf 1K 1/10W GND 100nf 330OHM-500MA GREEN-0603 GND100nf TSOC-PCB-SINGLE B3U-1000P-2P-SMD B3U-1000P-2P-SMD 10K 1/10W 10K 1/10W 10K 1/10W 10K 1/10W 10K 1/10W 10K 1/10W GND 10K 1/10W GND GND 220R 10K 1/10W 1K 1/10W GND YELLOW-0603 ESP-32S 10K 1/10W 47uGND 220R GND GND 3.2768KHZ 12pf 12pf GND GND CJT1117-3.3-SOT223 GND 10uf GND 47uGND 330OHM-500MA GND 330OHM-500MA 1K 1/10W 1K 1/10W 1K 1/10W 1K 1/10W 1K 1/10W 1K 1/10W 10K 1/10W 1K 1/10W 1K 1/10W C3C2 R22 C1 L2 LED2 C7 JTAG 1 2 3 4 5 6 7 8 9 10 11 12 13 14 15 16 1 1 2 2 RST1 1 2 2 USER R15 R17 ATN 6B RI 1C DCD 2C DSR 3C DTR 4C TXD 8C IO2 1B IO1 2B RTS 5C CTS 6C IRQ 5B SS2 3B SS1 4B CS 7B MOSI 10B MISO 9B SCK 8B GND 12B AGND 12C 3V3 11B RXD 7C SDA 10C SCL 9C 5V0 11C R16 Q1G$1 R10 R11 R14 R3 Q1G$2 R1 R20 R21 LED1 GND 1 3V3 2 EN 3 IO36/S_VP/ADC1_0 4 IO39/S_VN/ADC1_3 5 IO34/VDET1/ADC1_6 6 IO35/VDET2/ADC1_7 7 IO32/XTAL_32K/ADC1_4 8 IO33/XTAL_32K/ADC1_5 9 IO25/DAC1/ADC2_8 10 IO26/DAC2/ADC2_9 11 IO27/TOUCH7/ADC2_7 12 IO14/TOUCH6/ADC2_6 13 IO12/TOUCH5/ADC2_5 14 GND 15 IO13/TOUCH4/ADC2_4 16 SD2/SHD 17 SD3/SWP 18 CMD/SCS 19 GND 38 MOSI/IO23 37 SCL/IO22 36 TXD0/IO1 35 RXD0/IO3 34 SDA/IO21 33 NC 32 MISO/IO19 31 SCK/IO18 30 SS/IO5 29 TXD2IO17 28 RXD2/IO16 27 ADC2_0/TOUCH0/IO4 26 ADC2_1/TOUCH1/IO0 25 IO2 24 IO15/TOUCH3/ADC2_3 23 SD1/SDI 22 SD0/SDO 21 CLK/SCK 20 GND GND U2 R4 C6 R2 Y100 C101 C100 U1 GND 1 IN 3 OUT 2*2 C4C5 GND 5V0 L1 L3 R8R6 R12 R9R7R5 R13 R18 R19 VCC DTR RTS 3V3 IO0 ABCDE ABCDE 1 2 3 4 5 6 ABCDE ABCDE 1 2 3 4 5 6 ABCDE ABCDE 1 2 3 4 5 6 ABCDE ABCDE 1 2 3 4 5 6 GND GND GND GND GND GND GND GND GND Heartbeat LED Flash Programming & Reset Modes --------------------------------------------- | nDTR | nRTS | nRST | GPIO0 | --------------------------------------------- | 0 | 0 | 1 | 1 | | 0 | 1 | 1 | 0 | | 1 | 0 | 0 | 1 | | 1 | 1 | 1 | 1 | --------------------------------------------- 32,768 KHz Crystal (WCO/RTC Clock)

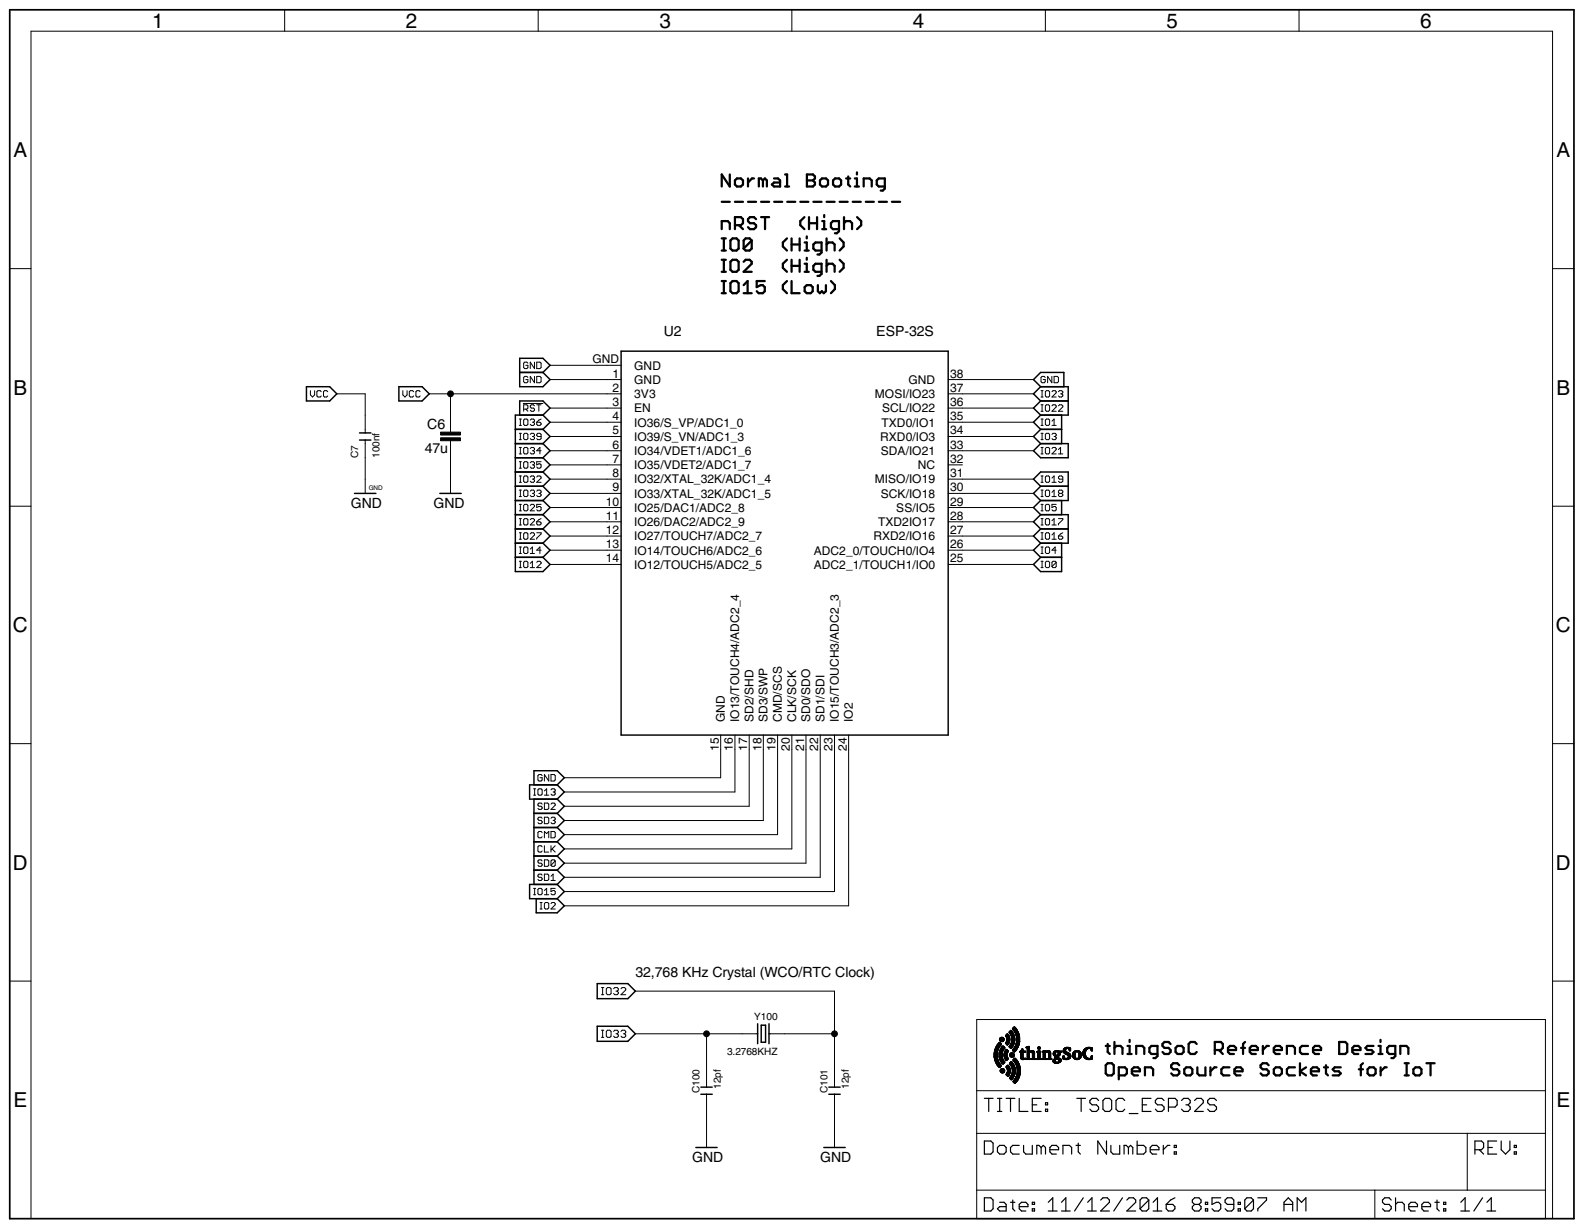
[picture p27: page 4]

100nf 1uf 1K 1/10W GND 100nf 330OHM-500MA GREEN-0603 GND100nf TSOC-PCB-SINGLE B3U-1000P-2P-SMD B3U-1000P-2P-SMD 10K 1/10W 10K 1/10W 10K 1/10W 10K 1/10W 10K 1/10W 10K 1/10W GND 10K 1/10W GND GND 220R 10K 1/10W 1K 1/10W GND YELLOW-0603 ESP-32S 10K 1/10W 47uGND 220R GND GND 3.2768KHZ 12pf 12pf GND GND CJT1117-3.3-SOT223 GND 10uf GND 47uGND 330OHM-500MA GND 330OHM-500MA 1K 1/10W 1K 1/10W 1K 1/10W 1K 1/10W 1K 1/10W 1K 1/10W 10K 1/10W 1K 1/10W 1K 1/10W C3C2 R22 C1 L2 LED2 C7 JTAG 1 2 3 4 5 6 7 8 9 10 11 12 13 14 15 16 1 1 2 2 RST1 1 2 2 USER R15 R17 ATN 6B RI 1C DCD 2C DSR 3C DTR 4C TXD 8C IO2 1B IO1 2B RTS 5C CTS 6C IRQ 5B SS2 3B SS1 4B CS 7B MOSI 10B MISO 9B SCK 8B GND 12B AGND 12C 3V3 11B RXD 7C SDA 10C SCL 9C 5V0 11C R16 Q1G$1 R10 R11 R14 R3 Q1G$2 R1 R20 R21 LED1 GND 1 3V3 2 EN 3 IO36/S_VP/ADC1_0 4 IO39/S_VN/ADC1_3 5 IO34/VDET1/ADC1_6 6 IO35/VDET2/ADC1_7 7 IO32/XTAL_32K/ADC1_4 8 IO33/XTAL_32K/ADC1_5 9 IO25/DAC1/ADC2_8 10 IO26/DAC2/ADC2_9 11 IO27/TOUCH7/ADC2_7 12 IO14/TOUCH6/ADC2_6 13 IO12/TOUCH5/ADC2_5 14 GND 15 IO13/TOUCH4/ADC2_4 16 SD2/SHD 17 SD3/SWP 18 CMD/SCS 19 GND 38 MOSI/IO23 37 SCL/IO22 36 TXD0/IO1 35 RXD0/IO3 34 SDA/IO21 33 NC 32 MISO/IO19 31 SCK/IO18 30 SS/IO5 29 TXD2IO17 28 RXD2/IO16 27 ADC2_0/TOUCH0/IO4 26 ADC2_1/TOUCH1/IO0 25 IO2 24 IO15/TOUCH3/ADC2_3 23 SD1/SDI 22 SD0/SDO 21 CLK/SCK 20 GND GND U2 R4 C6 R2 Y100 C101 C100 U1 GND 1 IN 3 OUT 2*2 C4C5 GND 5V0 L1 L3 R8R6 R12 R9R7R5 R13 R18 R19 VCC DTR RTS 3V3 IO0 ABCDE ABCDE 1 2 3 4 5 6 ABCDE ABCDE 1 2 3 4 5 6 ABCDE ABCDE 1 2 3 4 5 6 ABCDE ABCDE 1 2 3 4 5 6 GND GND GND GND GND GND GND GND GND Heartbeat LED Flash Programming & Reset Modes --------------------------------------------- | nDTR | nRTS | nRST | GPIO0 | --------------------------------------------- | 0 | 0 | 1 | 1 | | 0 | 1 | 1 | 0 | | 1 | 0 | 0 | 1 | | 1 | 1 | 1 | 1 | --------------------------------------------- 32,768 KHz Crystal (WCO/RTC Clock)

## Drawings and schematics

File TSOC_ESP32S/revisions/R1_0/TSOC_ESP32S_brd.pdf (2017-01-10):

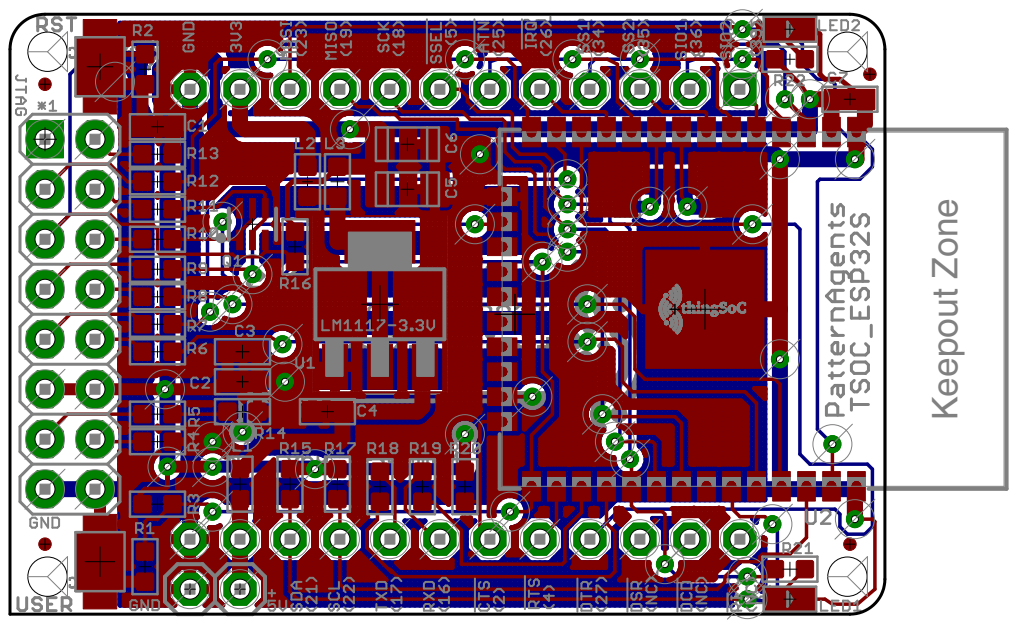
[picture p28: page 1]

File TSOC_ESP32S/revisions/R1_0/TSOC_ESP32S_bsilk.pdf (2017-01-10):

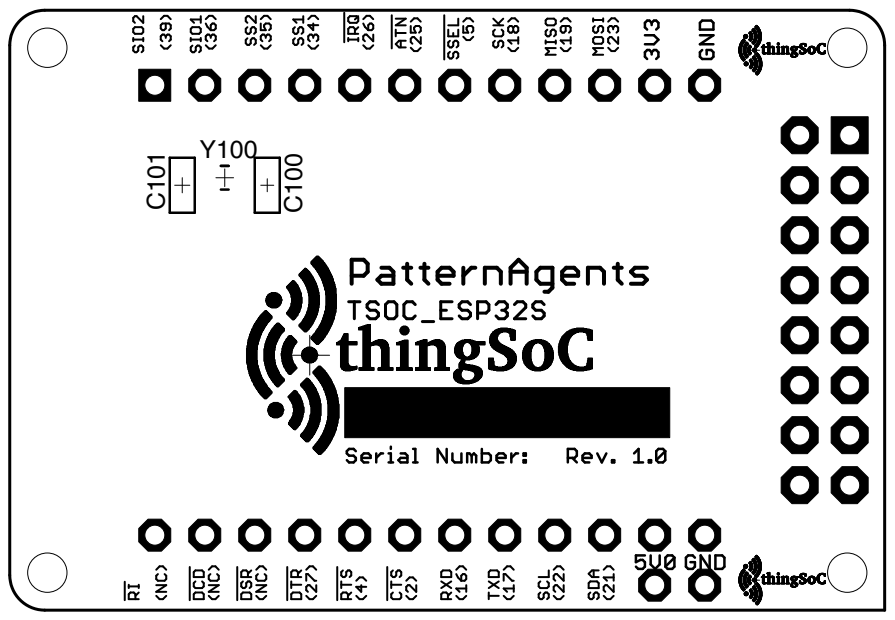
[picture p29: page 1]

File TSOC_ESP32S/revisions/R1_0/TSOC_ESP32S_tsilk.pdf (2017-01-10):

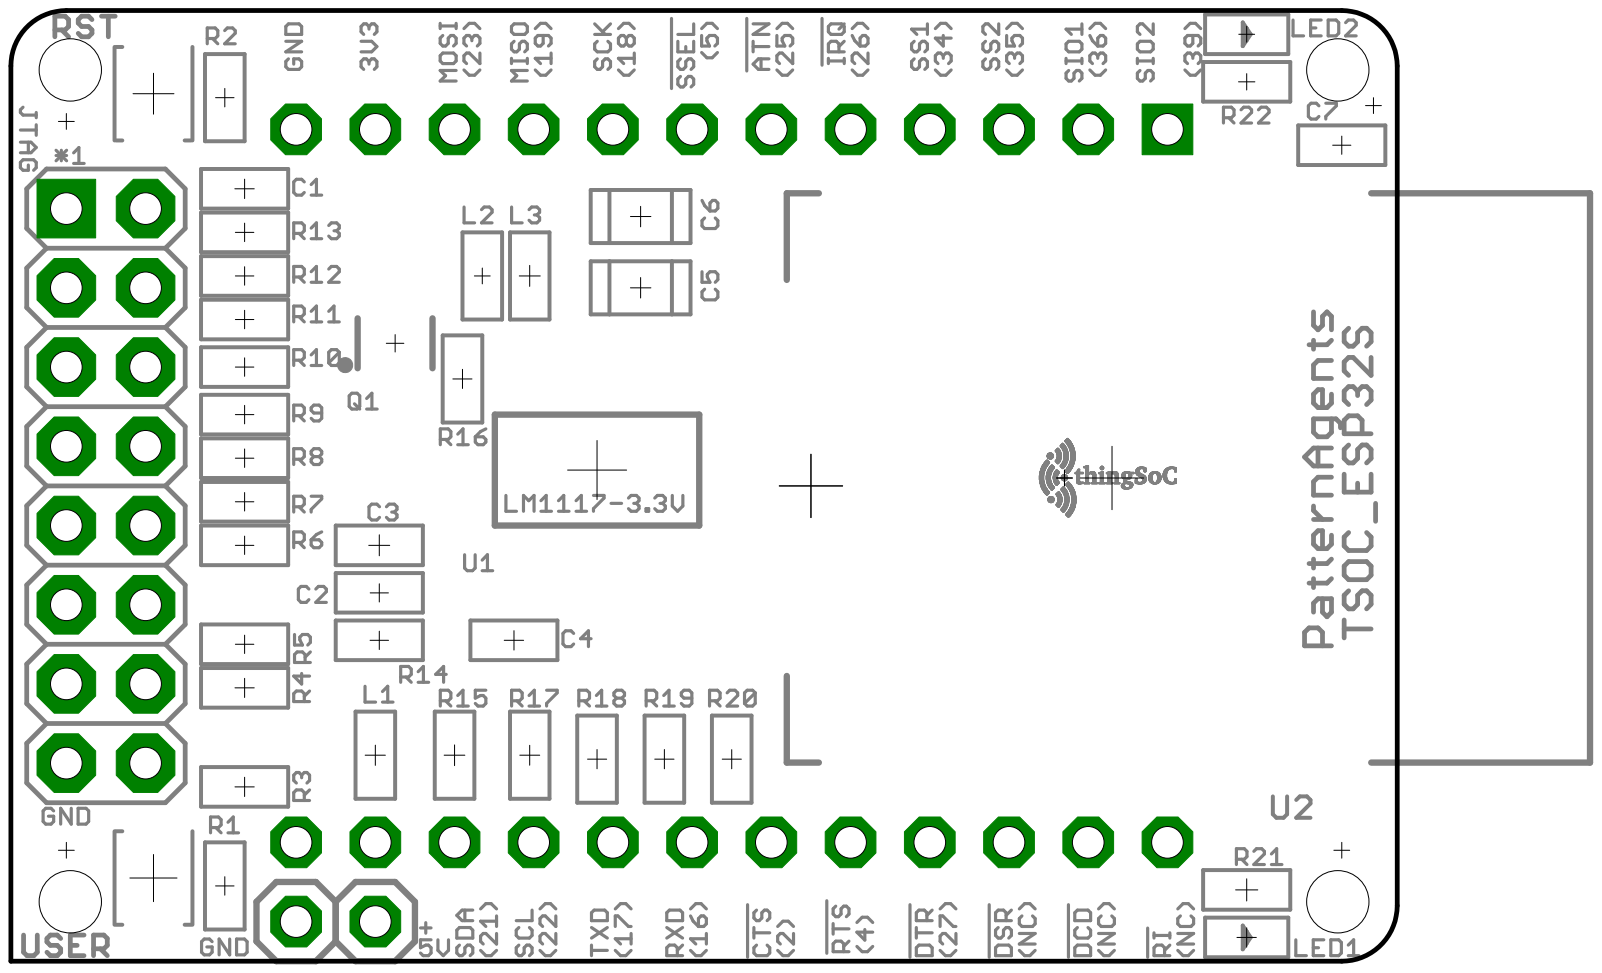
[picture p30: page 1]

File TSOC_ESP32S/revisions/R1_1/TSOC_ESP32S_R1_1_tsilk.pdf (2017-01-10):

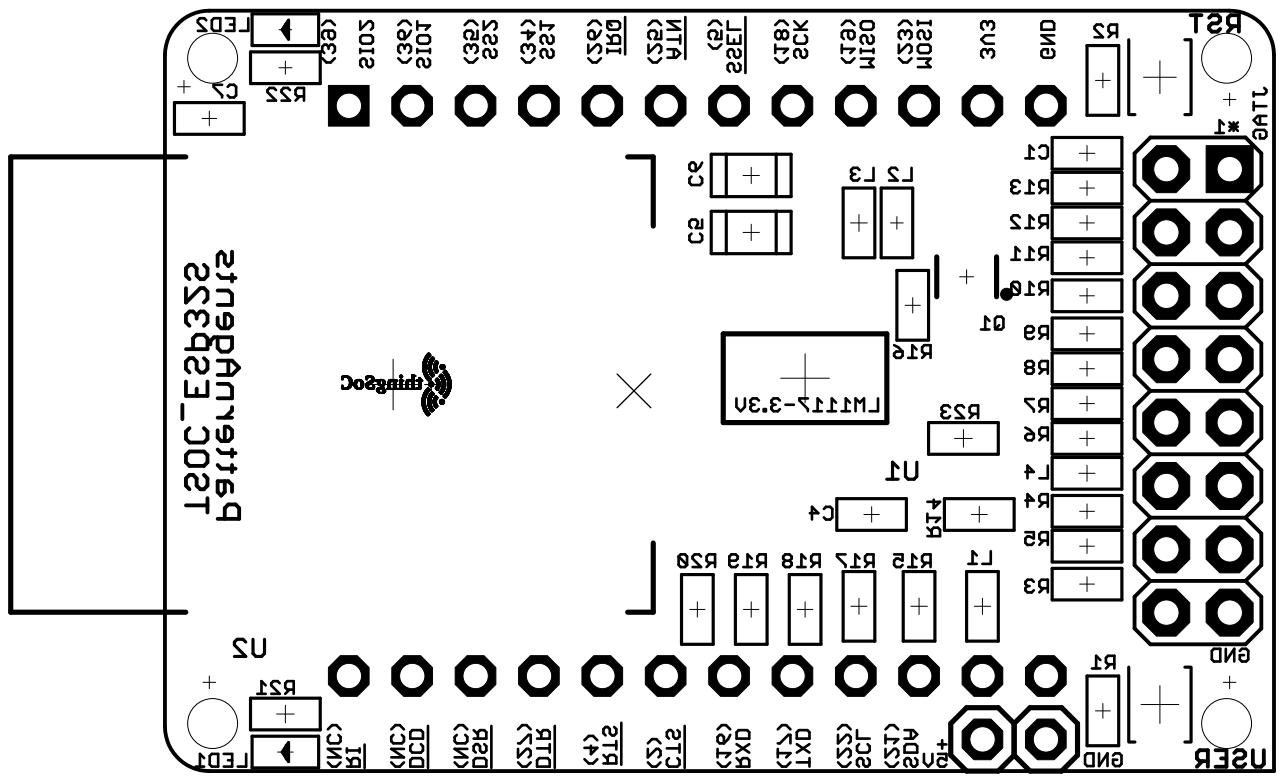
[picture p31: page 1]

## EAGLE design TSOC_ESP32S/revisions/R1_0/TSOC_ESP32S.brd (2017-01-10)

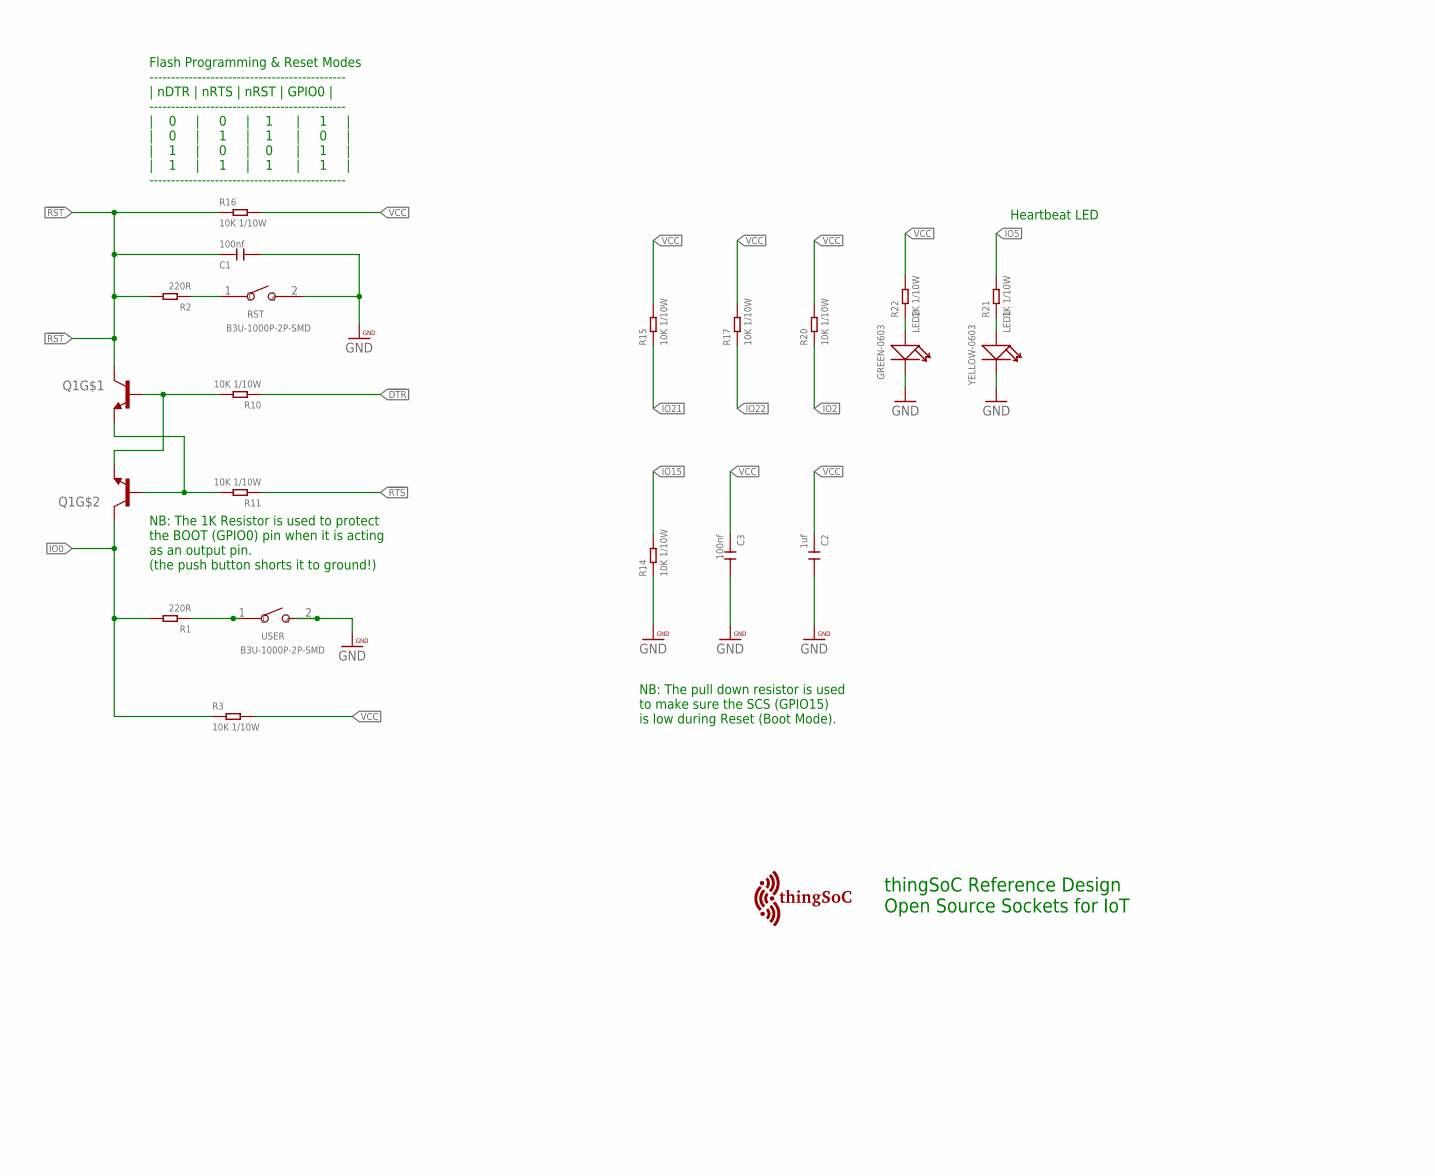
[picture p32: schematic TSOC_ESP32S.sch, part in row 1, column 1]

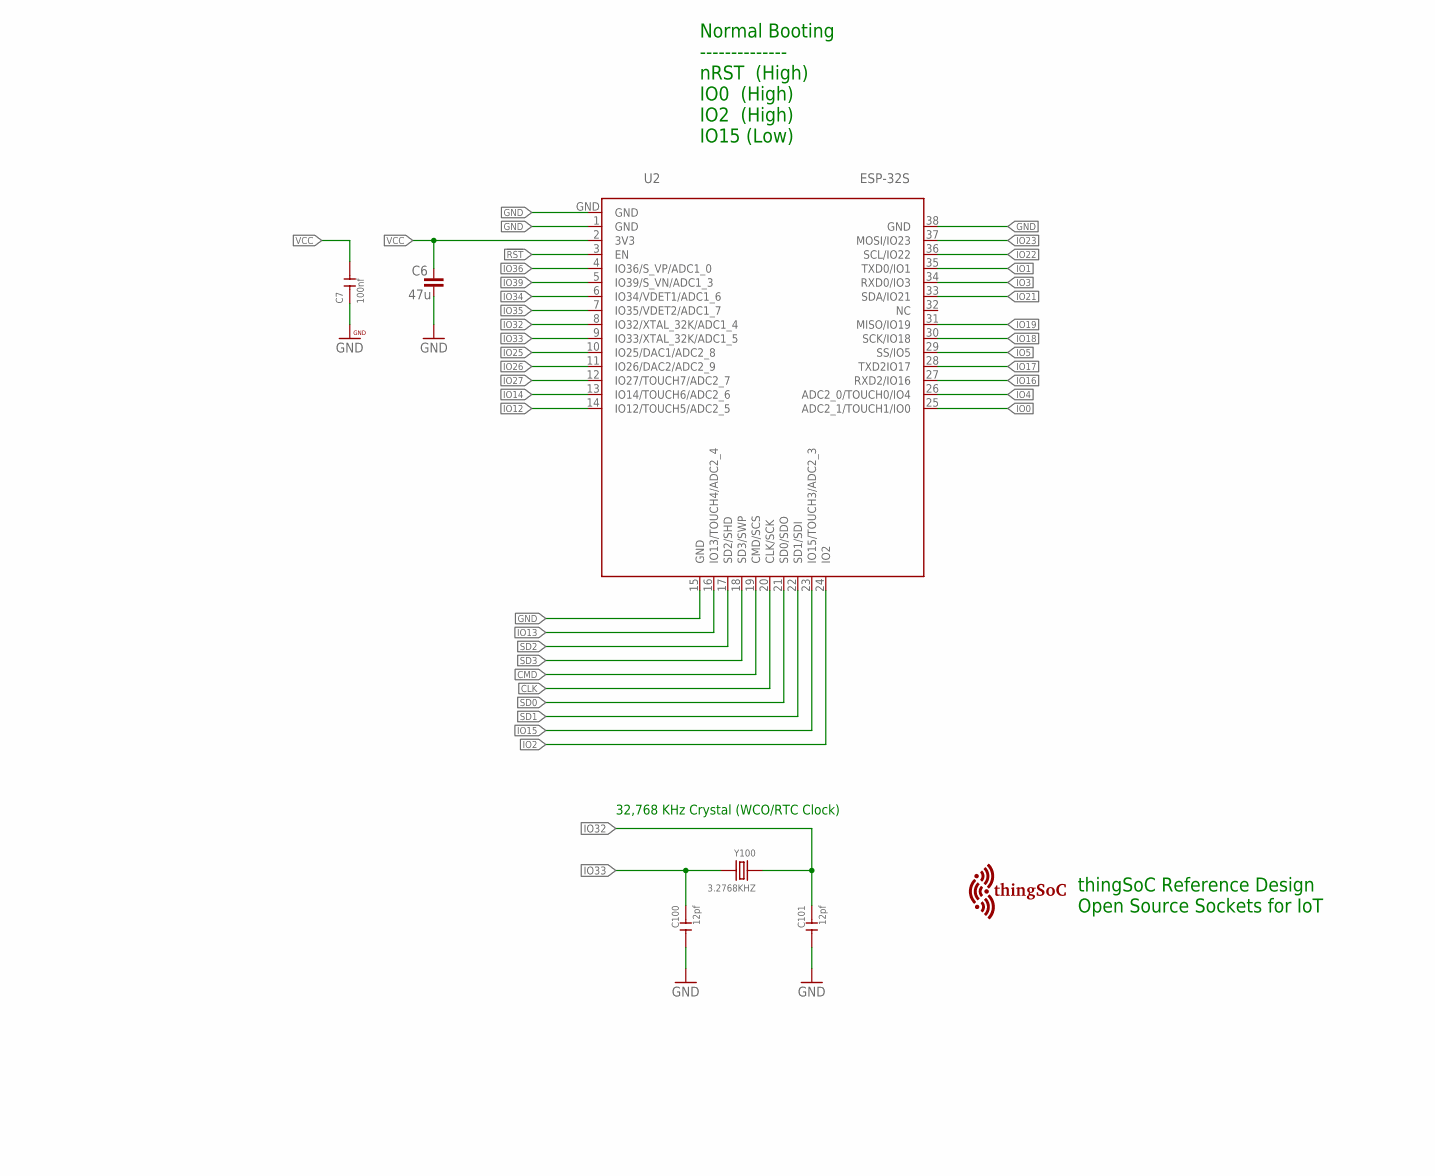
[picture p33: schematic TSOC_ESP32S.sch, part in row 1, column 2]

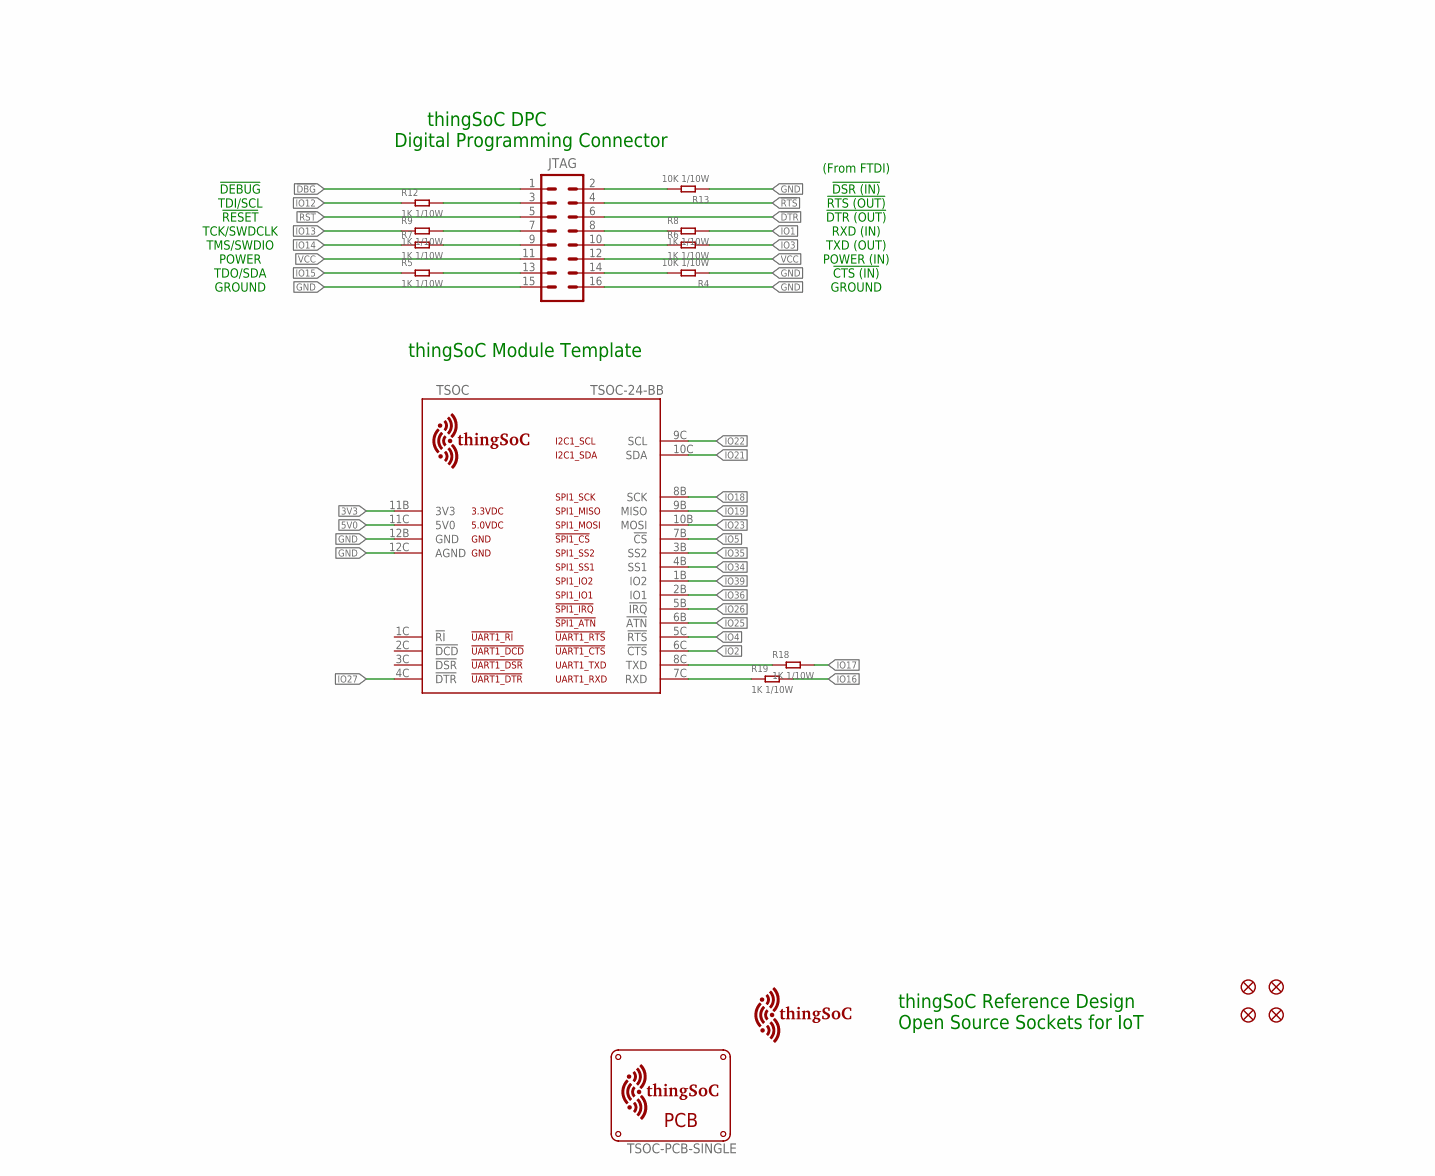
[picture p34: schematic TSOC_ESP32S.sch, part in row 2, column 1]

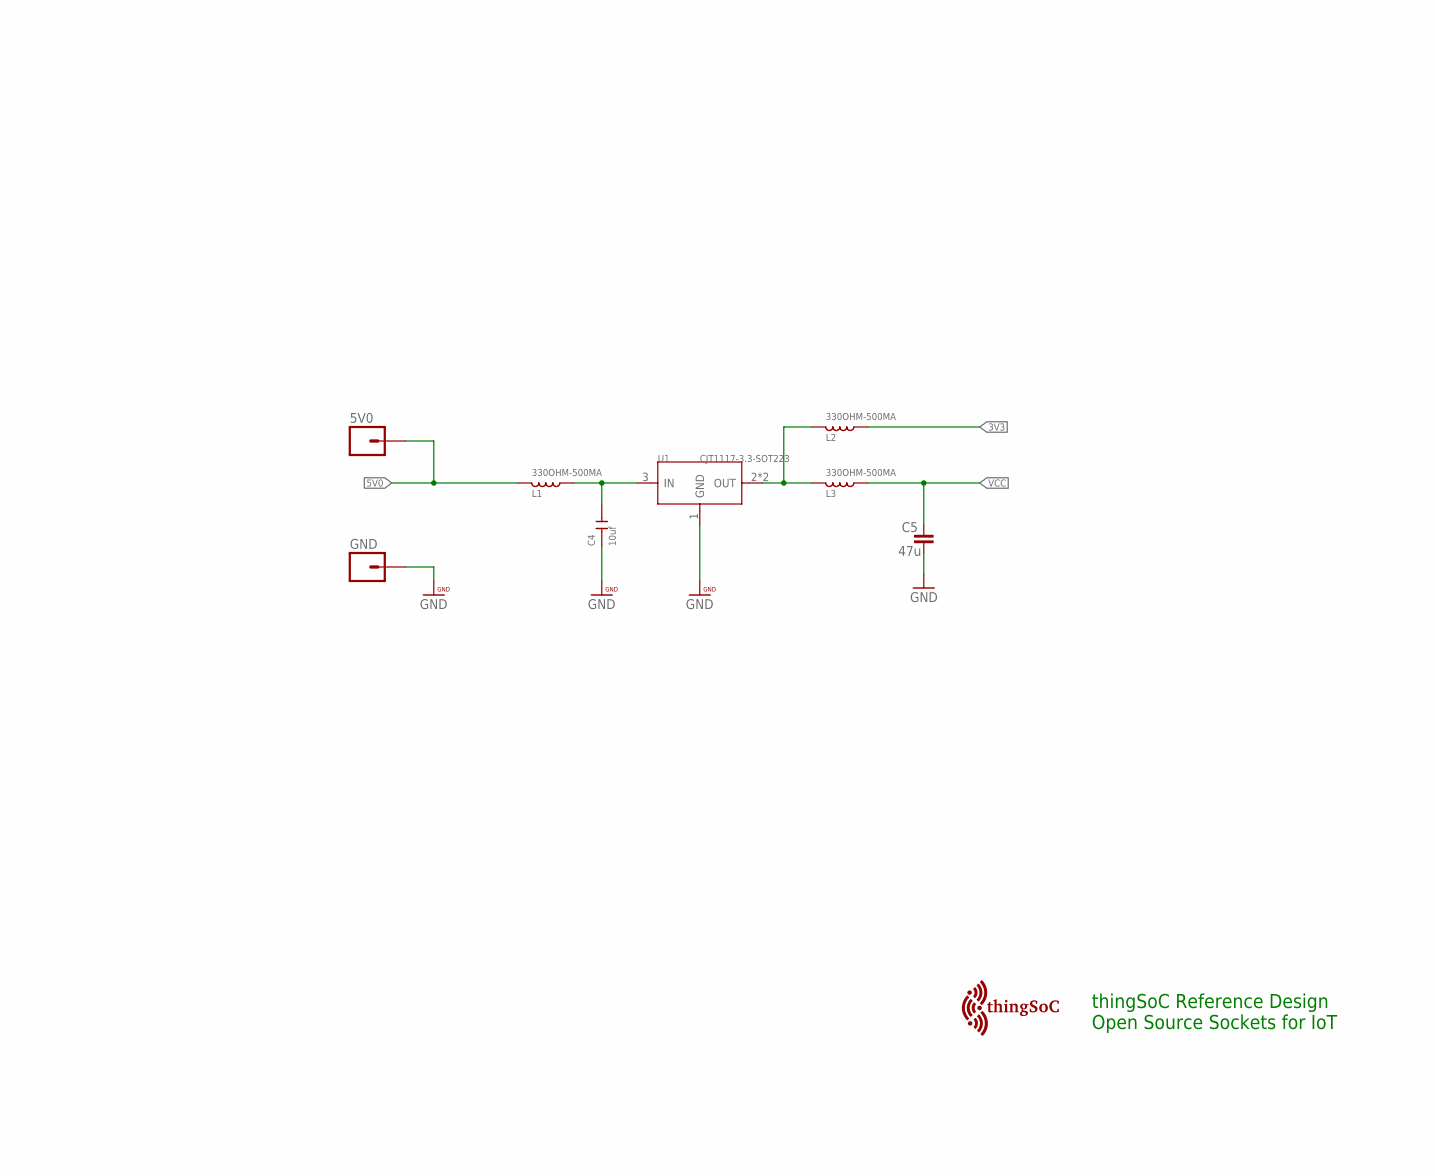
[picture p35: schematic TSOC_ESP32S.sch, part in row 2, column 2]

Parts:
5V0: M01PTH; 1X01
$$U$1, $$U$2: TSOC-LOGO-SMALL; TSOC-LOGO-SML
BRD: TSOC-PCB-SINGLE; TSOC-BB-BRD-DIM
C1, C3, C7: 100nf; C0603
C2: 1uf; C0603
C4: 10uf; C0603
C5, C6: 47u; C1206
C100, C101: 12pf; C0603
FID1, FID2, FID3, FID4: FIDUCIALUFIDUCIAL; MICRO-FIDUCIAL
GND: M01PTH; 1X01
JTAG: M08X2; 2X8
L1, L2, L3: 330OHM-500MA; L0603
LED1: YELLOW-0603; LED-0603
LED2: GREEN-0603; LED-0603
Q1: MMBT2222A; SOT363
R1, R2: 220R; R0603
R3, R4, R10, R11, R13, R14, R15, R16, R17, R20: 10K 1/10W; R0603
R5, R6, R7, R8, R9, R12, R18, R19, R21, R22: 1K 1/10W; R0603
RST: B3U-1000P-2P-SMD; SW2-2.6-3.0X2.5X1.2+0.4MM
TSOC: TSOC-24-BB; TSOC-BB-S24
U1: CJT1117-3.3-SOT223; SOT-223
U2: ESP-32S
U$101: TSOC-LOGO-SMALL; TSOC-LOGO-SML
U$102: TSOC-LOGO-LRG
USER: B3U-1000P-2P-SMD; SW2-2.6-3.0X2.5X1.2+0.4MM
Y100: 3.2768KHZ; X2-SMD-L2.0X1.2X0.55MM

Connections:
3V3: L2.2, TSOC.11B (3V3)
5V: C4.2, L1.2, U1.3 (IN)
5V0: 5V0.1, L1.1, TSOC.11C (5V0)
!CTSE: JTAG.14, R4.2
!DBG: JTAG.1
!DSRE: JTAG.2, R13.2
!DTR: JTAG.6, R10.1
!RST: C1.1, JTAG.5, Q1.3 (C), R2.2, R16.1, U2.3 (EN)
!RTS: JTAG.4, R11.1
CLK: U2.20 (CLK/SCK)
CMD: U2.19 (CMD/SCS)
GND: C1.2, C2.2, C3.2, C4.1, C5.1, C6.1, C7.1, C100.2, C101.2, GND.1, JTAG.15, JTAG.16, LED1.-, LED2.-, R4.1, R13.1, R14.1, RST.2, TSOC.12B (GND), TSOC.12C (AGND), U1.1 (GND), U2.1 (GND), U2.15 (GND), U2.38 (GND), U2.GND, USER.2
IO0: Q1.6 (C), R1.2, R3.1, U2.25 (ADC2_1/TOUCH1/IO0)
IO1: R8.2, U2.35 (TXD0/IO1)
IO1E: JTAG.8, R8.1
IO2: R20.1, TSOC.6C (!CTS), U2.24 (IO2)
IO3: R6.2, U2.34 (RXD0/IO3)
IO3E: JTAG.10, R6.1
IO4: TSOC.5C (!RTS), U2.26 (ADC2_0/TOUCH0/IO4)
IO5: R21.2, TSOC.7B (!CS), U2.29 (SS/IO5)
IO12: R12.1, U2.14 (IO12/TOUCH5/ADC2_5)
IO12E: JTAG.3, R12.2
IO13: R9.1, U2.16 (IO13/TOUCH4/ADC2_4)
IO13E: JTAG.7, R9.2
IO14: R7.1, U2.13 (IO14/TOUCH6/ADC2_6)
IO14E: JTAG.9, R7.2
IO15: R5.1, R14.2, U2.23 (IO15/TOUCH3/ADC2_3)
IO15E: JTAG.13, R5.2
IO16: R19.2, U2.27 (RXD2/IO16)
IO16E: R19.1, TSOC.7C (RXD)
IO17: R18.2, U2.28 (TXD2IO17)
IO17E: R18.1, TSOC.8C (TXD)
IO18: TSOC.8B (SCK), U2.30 (SCK/IO18)
IO19: TSOC.9B (MISO), U2.31 (MISO/IO19)
IO21: R15.1, TSOC.10C (SDA), U2.33 (SDA/IO21)
IO22: R17.1, TSOC.9C (SCL), U2.36 (SCL/IO22)
IO23: TSOC.10B (MOSI), U2.37 (MOSI/IO23)
IO25: TSOC.6B (!ATN), U2.10 (IO25/DAC1/ADC2_8)
IO26: TSOC.5B (!IRQ), U2.11 (IO26/DAC2/ADC2_9)
IO27: TSOC.4C (!DTR), U2.12 (IO27/TOUCH7/ADC2_7)
IO32: C101.1, U2.8 (IO32/XTAL_32K/ADC1_4), Y100.1
IO33: C100.1, U2.9 (IO33/XTAL_32K/ADC1_5), Y100.2
IO34: TSOC.4B (SS1), U2.6 (IO34/VDET1/ADC1_6)
IO35: TSOC.3B (SS2), U2.7 (IO35/VDET2/ADC1_7)
IO36: TSOC.2B (IO1), U2.4 (IO36/S_VP/ADC1_0)
IO39: TSOC.1B (IO2), U2.5 (IO39/S_VN/ADC1_3)
unnamed: LED1.+, R21.1
unnamed: R1.1, USER.1
unnamed: R2.1, RST.1
unnamed: LED2.+, R22.1
RES: Q1.1 (E), Q1.5 (B), R10.2
ROS: Q1.2 (B), Q1.4 (E), R11.2
SD0: U2.21 (SD0/SDO)
SD1: U2.22 (SD1/SDI)
SD2: U2.17 (SD2/SHD)
SD3: U2.18 (SD3/SWP)
VCC: C2.1, C3.1, C5.2, C6.2, C7.2, JTAG.11, JTAG.12, L3.2, R3.2, R15.2, R16.2, R17.2, R20.2, R22.2, U2.2 (3V3)
VOUT: L2.1, L3.1, U1.2 (OUT), U1.TER (OUT)

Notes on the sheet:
Heartbeat LED
thingSoC Reference Design Open Source Sockets for IoT
TDO/SDA
TDI/SCL
!RESET
TCK/SWDCLK
TMS/SWDIO
POWER
GROUND
!DEBUG
!DSR (IN)
!RTS (OUT)
!CTS (IN)
!DTR (OUT)
TXD (OUT)
RXD (IN)
POWER (IN)
thingSoC DPC Digital Programming Connector
Normal Booting -------------- nRST (High) IO0 (High) IO2 (High) IO15 (Low)
thingSoC Module Template
Flash Programming & Reset Modes --------------------------------------------- | nDTR | nRTS | nRST | GPIO0 | --------------------------------------------- | 0 | 0 | 1 | 1 | | 0 | 1 | 1 | 0 | | 1 | 0 | 0 | 1 | | 1 | 1 | 1 | 1 | ---------------------------------------------
NB: The 1K Resistor is used to protect the BOOT (GPIO0) pin when it is acting as an output pin. (the push button shorts it to ground!)
NB: The pull down resistor is used to make sure the SCS (GPIO15) is low during Reset (Boot Mode).
(From FTDI)
32,768 KHz Crystal (WCO/RTC Clock)

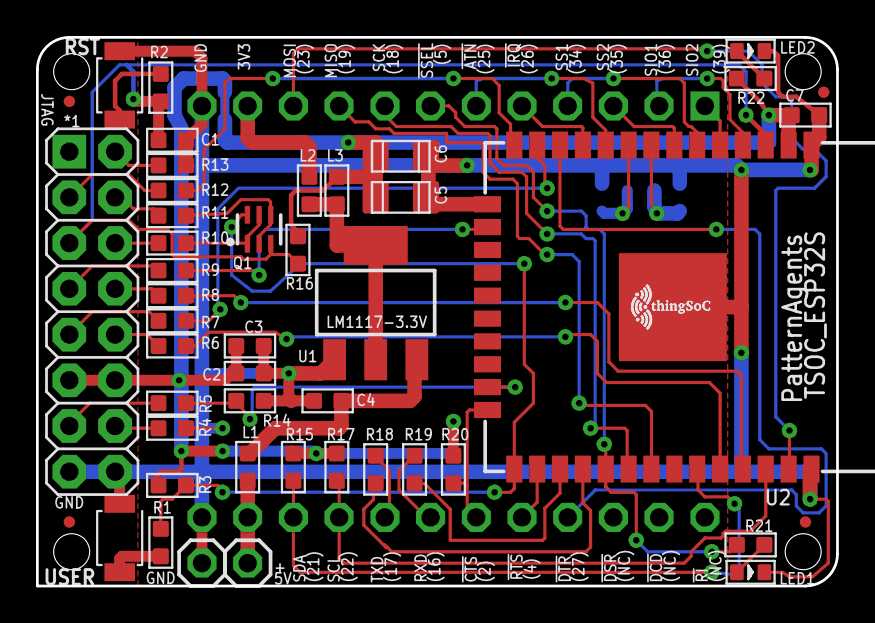
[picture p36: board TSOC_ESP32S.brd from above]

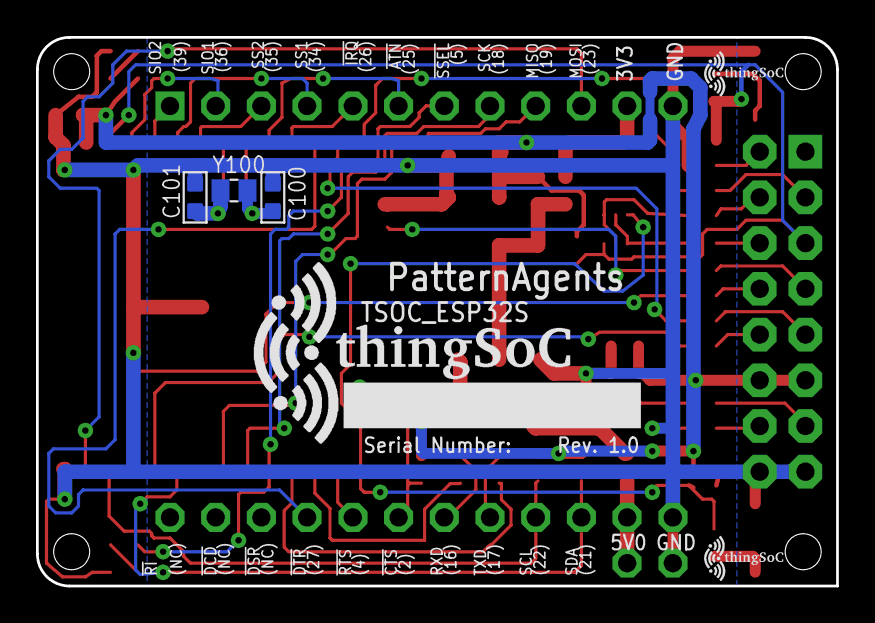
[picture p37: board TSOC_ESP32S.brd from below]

Board: 2 copper layers, 44.5 x 30.5 mm, 56 parts (6 on the bottom side), 51 nets.

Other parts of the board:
U$100: TSOC-LOGO-SMALL; TSOC-LOGO-SML

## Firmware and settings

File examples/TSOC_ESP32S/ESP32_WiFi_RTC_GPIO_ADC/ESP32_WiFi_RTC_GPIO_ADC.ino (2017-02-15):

/*************************************************************
 thingSoC Grovey ESP32 Wi-Fi embeddable module

 "thingSoC is a low-cost, highly-flexible and vendor agnostic 
 socket system for IoT product development. It consists of both 
 open-source hardware and software supporting many different 
 processor types and integrated development environments."

 "The thingSoC "Grovey Series" was designed as "Everyday Electronics", 
 a no-frills, low cost, approach to modular embedded product design. 
 thingSoC boards are similar in size to most break-out-boards (BOBs), 
 but feature a standardized stacking pinout, as well as a metadata 
 keystore (Embedis) to indicate what peripherals are installed,
 and other project configutation settings."

    Downloads, docs, tutorials: http://thingsoc.github.io
    Social networks:            @PatternAgents
    
 The thingSoC hardware system is licensed under Creative Commons 4.0
 This code and the Embedis firmware library is licensed under MIT license
 
 This example code is in the public domain.
 *************************************************************
  Blynk is a platform with iOS and Android apps to control
  Arduino, Raspberry Pi and the likes over the Internet.
  You can easily build graphic interfaces for all your
  projects by simply dragging and dropping widgets.
    Downloads, docs, tutorials: http://www.blynk.cc
    Blynk community:            http://community.blynk.cc
    Social networks:            http://www.fb.com/blynkapp
                                http://twitter.com/blynk_app
                                
  Blynk can provide your device with time data, like an RTC.
  Please note that the accuracy of this method is up to several seconds.
  App project setup:
    RTC widget (no pin required)
    Value Display M widget on V1
    Value Display M widget on V2
                                  
  Blynk library is licensed under MIT license
  This example code is in public domain.
 *************************************************************
  Additional Libraires Required for this example
  Use the Sketch->Include Library->Library Manager to install
  or simply unzip the libraries into your Arduino->libraries directory
 
  SimpleTimer Library:
    https://github.com/jfturcot/SimpleTimer
  Time keeping Library:
    https://github.com/PaulStoffregen/Time

 ------------------------------------------------------------
  Additonal Libraries required for supporting the Grovey GPIO  
  SX1509 GPIO Library:
  https://github.com/sparkfun/SparkFun_SX1509_Arduino_Library

 ------------------------------------------------------------
  Additonal Libraries required for supporting the Grovey ADC
  ADS1115/ADS1015 ADC Library:
  https://github.com/adafruit/Adafruit_ADS1X15 
  
 *************************************************************
 Grovey ESP32 WiFi RTC GPIO Sketch Overview

 Virtual Pins Used :
 V0  - Reserved for Debugging messages
 V1  - Current Real-Time
 V2  - Current Date
 V3  - Hardware Uptime in Hour/Min/Sec
 V4  - Hardware Uptime in Days
 V5  - "Connected" Virtual LED
 V6  - "Fault" Virtual LED
 V7  - ADC Channel Reading (Battery Voltage) (Not working yet on ESP32)
 V8  - "ledc" channel 1 (ESP32 PWM) (thingSoC/Mikrobus PWM physical pin)
 V9  - "ledc" channel 2 (ESP32 PWM) Onboard Physical (yellow) LED
 V10 - // sigmaDelta Digital to Analog (DAC) Channel 0
 V11 - // sigmaDelta Digital to Analog (DAC) Channel 1
 V12 - Mapped to physical GPIO Pin 2
 V13 - Available
 V14 - Available
 V15 - Available
 ------------------------------------------------------------  
 V16 - Grovey GPIO Jack J1 Signal A   - PWM Output
 V17 - Grovey GPIO Jack J1 Signal B   - Digital Input
 V18 - Grovey GPIO Jack J1 Power      - Digital Output
 V19 - Grovey GPIO Jack J1 BLUE LED   - PWM Output
 V20 - Grovey GPIO Jack J2 Signal A   - PWM Output
 V21 - Grovey GPIO Jack J2 Signal B   - Digital Input
 V22 - Grovey GPIO Jack J12 Power     - Digital Output
 V23 - Grovey GPIO Jack J12 RED LED   - PWM Output
 V24 - Grovey GPIO Jack J3 Signal A   - PWM Output
 V25 - Grovey GPIO Jack J3 Signal B   - Digital Input
 V26 - Grovey GPIO Jack J3 Power      - Digital Output
 V27 - Grovey GPIO Jack J3 GREEN LED  - PWM Output
 V28 - Grovey GPIO Jack J4 Signal A   - PWM Output
 V29 - Grovey GPIO Jack J4 Signal B   - Digital Input
 V30 - Grovey GPIO Jack J4 Power      - Digital Output
 V31 - Grovey GPIO Jack J4 YELLOW LED - PWM Output
 ------------------------------------------------------------
 V32 - Grovey ADC Jack J1 (Analog Input)
 V33 - Grovey ADC Jack J1 (Analog Input)
 V34 - Grovey ADC Jack J1 (Analog Input)
 V35 - Grovey ADC Jack J1 (Analog Input)
 ------------------------------------------------------------
   
 *************************************************************/

/* Grovey ESP32 Blynk WiFi defines */
#define BLYNK_PRINT Serial    // Comment this out to disable prints and save space
#define DEBUG_FLAG 0
#include <WiFi.h>
#include <WiFiClient.h>
#include <BlynkSimpleEsp32.h>
#include <SimpleTimer.h>
#include <TimeLib.h>
#include <WidgetRTC.h>

/* Grovey GPIO Board (Semtech SX1509 GPIO chip) */
#include <Wire.h>
#include <SparkFunSX1509.h> // Include SX1509 library
/* SX1509 I2C address (set by ADDR1 and ADDR0 (00 by default): */
  const byte SX1509_ADDRESS = 0x3E;  // SX1509 I2C address 00
//const byte SX1509_ADDRESS = 0x3F;  // SX1509 I2C address 01
//const byte SX1509_ADDRESS = 0x70;  // SX1509 I2C address 02
//const byte SX1509_ADDRESS = 0x71;  // SX1509 I2C address 03
SX1509 io; // Instantiate the SX1509

/* Library for the Grovey ADC board */
#include <Adafruit_ADS1015.h>
// Adafruit_ADS1115 ads;  /* Use this for the 16-bit version */
Adafruit_ADS1015 ads;     /* Use this for the 12-bit version */

// You should get Auth Token in the Blynk App.
// Go to the Project Settings (nut icon).
char auth[] = "XXXXXXXXXXXXXXXXXXXXXXXXXXXXXXXX";

// Your WiFi credentials.
// Set password to "" for open networks.
// Set security method to "WLAN_SEC_WPA2" if applicable
char ssid[] = "skynet";
char pass[] = "XXXXX";

// A timer instance to avoid flooding the Blynk Server
SimpleTimer timer;
// An RTC instance to obtain the real time from the Blynk Server
WidgetRTC rtc;
// A "virtual LED" instance to indicate connection state on pin V5
WidgetLED LED_connected(V5);
// A "virtual LED" instance to indicate the hardware state on pin V6
int fault, fault_last = 0;
WidgetLED LED_fault(V6);

// LED widgets for Grovey GPIO input pins
byte LED1_state, LED2_state, LED3_state, LED4_state = 0;
WidgetLED GPIO_Led1(17);
WidgetLED GPIO_Led2(21);
WidgetLED GPIO_Led3(25);
WidgetLED GPIO_Led4(29);

/* Global variables for the Uptime calculation */
long Days_up    = 0;
int  Hours_up   = 0;
int  Minutes_up = 0;
int  Seconds_up = 0;
int  HighMillis = 0;
int  Rollover   =0;

/* calculate the hardware uptime based on the millis counter */
void uptime(){
  /* Note an expected rollover if the millis counter */   
  if (millis()>=3000000000){ 
    HighMillis=1;
  }
  /* Flag the actual rollover of the millis counter */
  if (millis()<=100000&&HighMillis==1){
    Rollover++;
    HighMillis=0;
  }
  long secsUp = millis()/1000;
  Seconds_up = secsUp%60;
  Minutes_up = (secsUp/60)%60;
  Hours_up   = (secsUp/(60*60))%24;
  //First portion takes care of a rollover [around 50 days] 
  Days_up    = (Rollover*50)+(secsUp/(60*60*24));                      
};

// Digital clock display of the current time
// The time is obtained from the Blynk server using the WidgetRTC
// and then "echoed" back to the server using pins V1 (time) and V2 (Date)
void clockDisplay()
{
  // You can call hour(), minute(), ... at any time
  // Please see Time library examples for details
  char currentDate[16];
  char currentTime[16];
  char upDays[16];
  char upHours[16];
  sprintf(currentDate, "%04d/%02d/%02d", year(), month(), day());
  sprintf(currentTime, "%02d:%02d:%02d", hour(), minute(), second());
  // Send time to the App
  Blynk.virtualWrite(V1, currentTime);
  // Send date to the App
  Blynk.virtualWrite(V2, currentDate);
  uptime();
  sprintf(upDays, "%06d", Days_up);
  sprintf(upHours, "%02d:%02d:%02d", Hours_up, Minutes_up, Seconds_up);
  // Send uptime to the App
  Blynk.virtualWrite(V3, upHours);
  Blynk.virtualWrite(V4, upDays);
  
  // Note Bene : AnalogRead seems to crash WiFi - don't use right now...
  //ADC0 = GPIO36 = TSOC IO1
  // float ana = (analogRead(A0) / 4096) * 3.3 ;
  //ADC19 = GPIO26 = TSOC IRQ
  // int ana = analogRead(A19); // Not Working Yet...
  //float ana = 3.3;
  //Blynk.virtualWrite(V7, "3.30");

  // in order not to flood the blynk server, only update if changed
  // J1
  if ( io.digitalRead(1) != LED1_state) {
    LED1_state = io.digitalRead(1);
    if (LED1_state) {
      GPIO_Led1.on();
    } else {
      GPIO_Led1.off();
    }
  }
  if ( io.digitalRead(5) != LED2_state) {
    LED2_state = io.digitalRead(5);
    if (LED2_state) {
      GPIO_Led2.on();
    } else {
      GPIO_Led2.off();
    }
  }
  
  if ( io.digitalRead(9) != LED3_state) {
    LED3_state = io.digitalRead(9);
    if (LED3_state) {
      GPIO_Led3.on();
    } else {
      GPIO_Led3.off();
    }
  }
  if ( io.digitalRead(13) != LED4_state) {
    LED4_state = io.digitalRead(13);
    if (LED4_state) {
      GPIO_Led4.on();
    } else {
      GPIO_Led4.off();
    }
  }

  // You can't send any value at any time or you'll flood the Blynk Server
  // Please don't send more that 10 values per second.
  // So this is called from the SimpleTimer once per second
  int16_t adc0, adc1, adc2, adc3 = 0;                     // local variables to hold the current ADC readings
  int16_t adc0_last, adc1_last, adc2_last, adc3_last = 0; // local variables to hold the last ADC readings
  // Virtual Pin V32 is used to push the ADC0 reading  
  adc0 = ads.readADC_SingleEnded(0);
  if (adc0 != adc0_last) {
    adc0_last = adc0;
    Blynk.virtualWrite(V32, adc0);
    //Serial.print("AIN1: "); Serial.println(adc0);
  }  
  // Virtual Pin V33 is used to push the ADC1 reading  
  adc1 = ads.readADC_SingleEnded(1);
  if (adc1 != adc1_last) {
    adc1_last = adc1;
    Blynk.virtualWrite(V33, adc1);
    //Serial.print("AIN2: "); Serial.println(adc1);
  }  
  // Virtual Pin V34 is used to push the ADC2 reading  
  adc2 = ads.readADC_SingleEnded(2);
  if (adc2 != adc2_last) {
    adc2_last = adc2;
    Blynk.virtualWrite(V34, adc2);
    //Serial.print("AIN3: "); Serial.println(adc3);
  }    
  // Virtual Pin V35 is used to push the ADC3 reading  
  adc3 = ads.readADC_SingleEnded(3);
  if (adc3 != adc3_last) {
    adc3_last = adc3;
    Blynk.virtualWrite(V35, adc3);
    //Serial.print("AIN4: "); Serial.println(adc3);
  }    
}

// "ledc" channel 1 (ESP32 PWM)
// test "fault" LED to indicate out of range values
BLYNK_WRITE(V8) {
  int pinData = param.asInt();
  ledcWrite(1, pinData);
  // we're using ledC in eight (8) bit mode
  // so use "fault" to indiacte an out-of-bounds parameter
  // this is just an arbitrary example usage...
  if (pinData > 255) {
    fault = 1;
  } else {
    fault = 0;
  } 
  
  // only send updates when value changes...
  if (fault_last != fault) {
     fault_last = fault;
     if (fault) {   
       LED_fault.on();
     } else {
       LED_fault.off();
     }
  }
}

// "ledc" channel 2 (ESP32 PWM) Onboard Physical (yellow) LED
BLYNK_WRITE(V9) {
  int pinData = param.asInt();
  ledcWrite(2, pinData);
}

// sigmaDelta Digital to Analog (DAC) Channel 0
BLYNK_WRITE(V10) {
  int pinData = param.asInt();
  sigmaDeltaWrite(0, pinData);
}

// sigmaDelta Digital to Analog (DAC) Channel 1
BLYNK_WRITE(V11) {
  int pinData = param.asInt();
  sigmaDeltaWrite(1, pinData);
}

// Virtual pin 12 mapped to GPIO2 physical pin
// Yes, while this can be done directly to hardware pins
// in Blynk - it makes hardware changes easier to implement
// without changing/editing your Blynk GUI layout -
// this is an (arbitrary) example of how to do that... 
BLYNK_WRITE(V12) {
  int pinData = param.asInt();
  if (pinData == 0) {
    digitalWrite(2, LOW);
  } else {
    digitalWrite(2, HIGH);
  }
}

BLYNK_WRITE(V16) {
  byte bright;
  int pinData = param.asInt();
  bright = 255 - (byte) pinData;
  io.analogWrite(0, bright);
}

BLYNK_WRITE(V18) {
  int pinData = param.asInt();
  if (pinData == 0) {
    io.digitalWrite(2, LOW);
  } else {
    io.digitalWrite(2, HIGH);
  }
}

BLYNK_WRITE(V19) {
  byte bright;
  int pinData = param.asInt();
  bright = 255 - (byte) pinData;
  io.analogWrite(3, bright);
}

BLYNK_WRITE(V20) {
  byte bright;
  int pinData = param.asInt();
  bright = 255 - (byte) pinData;
  io.analogWrite(4, bright);
}

BLYNK_WRITE(V22) {
  int pinData = param.asInt();
  if (pinData == 0) {
    io.digitalWrite(6, LOW);
  } else {
    io.digitalWrite(6, HIGH);
  }
}
BLYNK_WRITE(V23) {
  byte bright;
  int pinData = param.asInt();
  bright = 255 - (byte) pinData;
  io.analogWrite(7, bright);
}

BLYNK_WRITE(V24) {
  byte bright;
  int pinData = param.asInt();
  bright = 255 - (byte) pinData;
  io.analogWrite(8, bright);
}

BLYNK_WRITE(V26) {
  int pinData = param.asInt();
  if (pinData == 0) {
    io.digitalWrite(10, LOW);
  } else {
    io.digitalWrite(10, HIGH);
  }
}

BLYNK_WRITE(V27) {
  byte bright;
  int pinData = param.asInt();
  bright = 255 - (byte) pinData;
  io.analogWrite(11, bright);
}

BLYNK_WRITE(V28) {
  byte bright;
  int pinData = param.asInt();
  bright = 255 - (byte) pinData;
  io.analogWrite(12, bright);
}

BLYNK_WRITE(V30) {
  int pinData = param.asInt();
  if (pinData == 0) {
    io.digitalWrite(14, LOW);
  } else {
    io.digitalWrite(14, HIGH);
  }
}

BLYNK_WRITE(V31) {
  byte bright;
  int pinData = param.asInt();
  bright = 255 - (byte) pinData;
  io.analogWrite(15, bright);
}

void setup()
{
  // Debug console : note the the Arduino IDE default is 115200 baud
  // Change it if your requirements are different...
  Serial.begin(115200);
  Serial.println("Starting Grovey GPIO Board ... ");
  // Initialize the SX1509, returns "1" when successful, "0" if not.
  if (io.begin(SX1509_ADDRESS, 255)==0) {
    // If we fail to initialize the SX1509 chip,
    // then loop forever, slow blinking the built-in LED on the CPU board
    while (1) {
      delay(1000);
    }
  }
  /* Initialize the pinModes of the Grovey GPIO Board */
  io.pinMode(0,  ANALOG_OUTPUT);
  io.pinMode(1,  INPUT);
  io.pinMode(2,  OUTPUT);
  io.pinMode(3,  ANALOG_OUTPUT);
  io.pinMode(4,  ANALOG_OUTPUT);
  io.pinMode(5,  INPUT);
  io.pinMode(6,  OUTPUT);
  io.pinMode(7,  ANALOG_OUTPUT);
  io.pinMode(8,  ANALOG_OUTPUT);
  io.pinMode(9,  INPUT);
  io.pinMode(10, OUTPUT);
  io.pinMode(11, ANALOG_OUTPUT);
  io.pinMode(12, ANALOG_OUTPUT);
  io.pinMode(13, INPUT);
  io.pinMode(14, OUTPUT);
  io.pinMode(15, ANALOG_OUTPUT);  
  Serial.println("Grovey GPIO Board Running... ");

  // The ADC input range (or gain) can be changed via the following
  // functions, but be careful never to exceed VDD +0.3V max, or to
  // exceed the upper and lower limits if you adjust the input range!
  // Setting these values incorrectly may destroy your ADC!
  //                                                                ADS1015  ADS1115
  //                                                                -------  -------
  ads.setGain(GAIN_TWOTHIRDS);  // 2/3x gain +/- 6.144V  1 bit = 3mV      0.1875mV (default)
  // ads.setGain(GAIN_ONE);        // 1x gain   +/- 4.096V  1 bit = 2mV      0.125mV
  // ads.setGain(GAIN_TWO);        // 2x gain   +/- 2.048V  1 bit = 1mV      0.0625mV
  // ads.setGain(GAIN_FOUR);       // 4x gain   +/- 1.024V  1 bit = 0.5mV    0.03125mV
  // ads.setGain(GAIN_EIGHT);      // 8x gain   +/- 0.512V  1 bit = 0.25mV   0.015625mV
  // ads.setGain(GAIN_SIXTEEN);    // 16x gain  +/- 0.256V  1 bit = 0.125mV  0.0078125mV
  Serial.println("Starting ADS ADC... "); 
  ads.begin();
  Serial.println("Grovey ADC Board Running... ");
  
  Serial.println("Starting Blynk... ");
  Blynk.begin(auth, ssid, pass);
  // use this is you need WPA2
  //Blynk.begin(auth, ssid, pass, security);
  
  Serial.println("Blynk Running... ");
  while(Blynk.connect() == false);      // wait for Blynk to connect to Server
  Serial.println("Blynk Connected... ");

  // Begin synchronizing time
  rtc.begin();
  Blynk.syncAll();
  
  // Other Time library functions can be used, like:
  //   timeStatus(), setSyncInterval(interval)...
  // Read more: http://www.pjrc.com/teensy/td_libs_Time.html
  // Update Display digital clock every 1.5 seconds
  // we do this to avoid flooding the Blynk server with too much data
  timer.setInterval(1500L, clockDisplay);

  /* setup ESP32 pin modes */
  /* Setup two DAC channels GPIO25=ADC18, GPIO26=ADC19 */
  /* setup channel 0 with frequency 312500 Hz */
  sigmaDeltaSetup(0, 312500);
  //attach pin ADC18/GPIO25 to channel 0
  sigmaDeltaAttachPin(18,0);
  //initialize channel 0 to off
  sigmaDeltaWrite(0, 0);
  //setup channel 1 with frequency 312500 Hz
  sigmaDeltaSetup(1, 312500);
  //attach pin ADC19/GPIO26 to channel 1
  sigmaDeltaAttachPin(19,1);
  //initialize channel 1 to off
  sigmaDeltaWrite(1, 0);

  // Setup "ledC" PWM channel on GPIO4 & GPIO5
  ledcSetup(1, 50, 8); // channel 1, 50 Hz, 8-bit depth
  ledcAttachPin(4, 1);   // GPIO 4 on channel 1
  // N.B. GPIO5 is also SPI SS - comment the next two lines out if using SPI!
  ledcSetup(2, 50, 8); // channel 2, 50 Hz, 8-bit depth
  ledcAttachPin(5, 2);  // GPIO 5 on channel 2
  
  /* Setup digital/GPIO output on GPIO2 physical pin */
  pinMode( 2,   OUTPUT);
  /* Note Bene : AnalogRead seems to crash WiFi - don't use right now on ESP32 2/9/2017 */
  // pinMode( A0,  ANALOG);
  // pinMode( A19, ANALOG);

  // Since ADC Volt measurement not working yet on ESP32 , we'll do this once in setup...
  Blynk.virtualWrite(V7, "3.30");
  GPIO_Led1.off();
  GPIO_Led2.off();
  GPIO_Led3.off();
  GPIO_Led4.off();    
  LED_fault.off();
  LED_connected.on();
}

/* gotta love a "clean" main loop! */
void loop()
{
  Blynk.run();
  timer.run();
}

/* end of ESP32_WiFi_RTC.ino */

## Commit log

2017-01-14 update documetation
    [TSOC_ESP32S_pinout.ods]
2017-02-12 update arduino/blynk example
2019-02-20 2019 update
    [TSOC_ESP32S_pinout.ods]

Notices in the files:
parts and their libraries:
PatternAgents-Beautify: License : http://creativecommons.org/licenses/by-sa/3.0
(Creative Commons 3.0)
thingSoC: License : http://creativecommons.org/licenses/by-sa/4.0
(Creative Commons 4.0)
